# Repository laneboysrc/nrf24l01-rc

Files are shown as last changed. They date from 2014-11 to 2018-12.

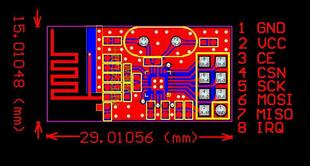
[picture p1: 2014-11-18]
doc/NRF24L01-module.jpg

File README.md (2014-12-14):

# nRF24-based RC car receiver, compatible with HobbyKing HK310 and Turnigy 3XS

This project includes **electronics** and **firmware** to build **surface RC receivers** that can replace the HobbyKing [HKR3000](http://hobbyking.com/hobbyking/store/__12187__HK_3000_3ch_2_4ghz_FHSS_RX_suit_the_HK310_Transmitter.html) and [XR3100](http://hobbyking.com/hobbyking/store/__22910__HK3100_3ch_2_4ghz_FHSS_Micro_RX_suits_HK310_Turnigy_3XS_TX_.html) receivers. They can be used with the [HK300](http://hobbyking.com/hobbyking/store/__12177__HK_300_3_Channel_2_4ghz_FHSS_Ground_Radio.html), [HK310](http://hobbyking.com/hobbyking/store/__12181__HK_310_3_Channel_2_4ghz_FHSS_Ground_Radio.html) and [Turnigy 3XS](http://hobbyking.com/hobbyking/store/__24905__Turnigy_3XS_FHSS_2_4GHz_3_Channel_Radio_System.html) RC car radio systems.

The receivers make use of off-the-shelf inexpensive RF modules.

Two variants are provided:

- [lpc812-nrf24l01](lpc812-nrf24l01-receiver/): NRF24L01+ module plus a [NXP LPC812](http://www.nxp.com/products/microcontrollers/cortex_m0_m0/series/LPC800.html) MCU
- [nrf24le1](nrf24le1-receiver/): Using a NRF24LE1 module (integrated 8051 MCU)

Technical information about the inner working of the receivers can be found
in **[hkr3000-info.md](doc/hkr3000-info.md)**.

## Advantages of the NRF24L01+ - LPC812 version

- Easily obtainable and very low cost NRF module (less than USD 1 including shipping in qty 10 on eBay, Aliexpress)
- Very precise servo pulses due to LPC812 timer hardware
- ARM Cortex-M0 32-bit CPU is easy to program for with the GCC ARM compiler
- No proprietary programmer required as the MCU has a ROM bootloader that can be flashed with an  USB-to-serial dongle
- Servo pulses can be updated down to every 5 ms (200 Hz). In theory this may provide better response but in practice the transmitter would need to be modified to fully take
advantage of this fact.
- UART output using the LANE Boys RC [preprocessor protocol](http://laneboysrc.blogspot.com/2012/12/pre-processor-for-diy-rc-light.html), e.g. to hook up the [DIY RC light controller](https://github.com/laneboysrc/rc-light-controller) with a single servo cable.

Downsides:

- Requires a PCB and intermediate SMD soldering skills
- No CPPM output (but it has a UART output that can carry CPPM-like data and more)

## Advantages of the NRF24LE1 version

- Low part count: NRF24LE1 module, voltage regulator, a few capacitors; done!
- Simple to build even on a breadboard
- CPPM output
- UART output using the LANE Boys RC [preprocessor protocol](http://laneboysrc.blogspot.com/2012/12/pre-processor-for-diy-rc-light.html), e.g. to hook up the [DIY RC light controller](https://github.com/laneboysrc/rc-light-controller) with a single servo cable. Baudrate is limited to 38400 though.

Downsides:

- NRF24LE1 module is more expensive than NRF24L01 and harder to find
- Requires special programming hardware. Multiple open-source versions can be found on the Internet.
- Servo pulses are software timed, hence slightly jittery despite using interrupts. Note that the firmware included in this project is improved over the original HKR3000 and XR3100 firmware, which regularly extends servo pulses by 16 us due to poor interrupt logic implementation.
- For the PCB provided in this project you need to get the NRF24LE1 module version that has an SMD crystal (size 21 x 15 mm)

The NRF24LE1 firmware included in this project can be compiled to be compatible with the HKR3000 and XR3100 hardware. However, since those receivers use the OTP version (NRF24LE1G) one would have to replace the chip with the NR24LE1E versions to be able to use it.

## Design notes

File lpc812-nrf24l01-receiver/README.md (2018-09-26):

The LPC812-based receiver comes in two variants:

3/4 channel version
- Supports the original HobbyKing HK310 protocol
- Supports the LANE Boys RC 4 channel protocol
- Based on 16 pin TSSOP LPC812
- Uses the cheap nRF24 modules with the 2x4 pinheader

8 channel version
- Supports the original HobbyKing HK310 protocol
- Supports the LANE Boys RC 4 channel protocol
- Supports the LANE Boys RC 8 channel protocol
- Based on 20 pin TSSOP LPC812
- Uses a different, smaller nRF24L01 module that comes variants
with PCB antenna and IPX connector

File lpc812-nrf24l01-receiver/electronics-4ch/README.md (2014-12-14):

# Schematics and PCB layout for the NRF24L01+ - LPC812 receiver

The source files are for [Kicad](http://www.kicad-pcb.org).

For convenience the [schematics](SCHEMATICS.pdf) are also available as PDF.

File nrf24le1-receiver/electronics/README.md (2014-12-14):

# Schematics and PCB layout for the NRF24LE1 receiver

The source files are for [Kicad](http://www.kicad-pcb.org).

For convenience the [schematics](SCHEMATICS.pdf) are also available as PDF.

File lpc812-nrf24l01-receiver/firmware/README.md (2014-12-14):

# Tools required to build the LPC812 firmware

**Note: a pre-compiled firmware is available for download [here](receiver.hex).**

- **GCC for ARM** [https://launchpad.net/gcc-arm-embedded/](https://launchpad.net/gcc-arm-embedded/)

- **GNU Make** [https://www.gnu.org/software/make/](https://www.gnu.org/software/make/);
  Windows executable is available at [http://gnuwin32.sourceforge.net/packages/make.htm](http://gnuwin32.sourceforge.net/packages/make.htm)

- Optional: LCP81x-ISP [https://github.com/laneboysrc/LPC81x-ISP-tool](https://github.com/laneboysrc/LPC81x-ISP-tool) Alternatively you can use any tool that can flash the LPC812 via ISP.

- Windows users: **rm.exe** from [coreutils](http://gnuwin32.sourceforge.net/downlinks/coreutils-bin-zip.php).

# Building the firmware

Running ``make`` in a console window in this directory builds the firmware. The resulting *receiver.bin* and *receiver.hex* are located in the build directory.

Running ``make program`` flashes the firmware, assuming you are using the *LCP81x-ISP* tool.

It may be advisable to check the ``makefile`` whether the settings are desired for your application.

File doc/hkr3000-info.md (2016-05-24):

# HKR3000 and XR3100 receiver technical information

Both receivers use the [Nordic NRF24LE1](http://www.nordicsemi.com/eng/Products/2.4GHz-RF/nRF24LE1) RF chip. It is a composite device containing the RF logic of the popular NRF24L01+ and an 8051 MCU.

Unfortunately both receivers use the OTP version, not the Flash version, so they can not be re-programmed.

The HKR3000 has an LNA (Low Noise Amplifier), the XR3100 connects the antenna directly the NRF24LE1. In theory this should give the HKR3000 better range, but in practice I haven't noticed any difference between them.

## Transmitter

The HK310 and 3XS transmitter also contains an NRF24LE1, which receives channel 1, 2 and 3 data (we call this **stick data**) from another microcontroller via UART. The stick data over the UART is 12 bit, with center (1500 us) being 0x465.
The NRF24LE1 in the transmitter converts this stick data into a 16-bit timer value that can be directly loaded into one of the timers on the NRF24LE1's 8051 MCU. These 16-bits are sent over the air. The timer tick is assumed to be 750 ns (16 MHz / 12).

The algorithm to calculate the timer value is as follows:

        timer_value = (uart_data * 14 / 10) + 0xf200

## NRF24 RF configuration

- 10 byte payload size
- 5 byte address size
- 2 byte CRC
- 20 hop channels
- One hop every 5 ms
- Transmitter sends three packets every 5 ms: two stick (or failsafe) packets, one bind packet
- Uni-directional data transfer (transmitter only transmits, receiver only receives; no acknowledgement or telemetry)

## Stick and failsafe packet format

Example payload of actual captured packets (10 bytes payload):
```
f1 f7 4a f8 8e f5 b8 55 67 0f     stick packet
40 f8 40 f8 8e f5 b8 aa 5a 0f     failsafe packet
```

Stick data:
```
0     1     2     3     4     5     6    7    8    9
ST-l  ST-h  TH-l  TH-h  CH3-l CH3-h ???  0x55 0x67 ???
                                         ^^^^
                                         Packet id
```
Bytes 6, 8 and 9 are ignored by the receiver

Failsafe data:
```
0     1     2     3     4     5     6    7    8    9
ST-l  ST-h  TH-l  TH-h  CH3-l CH3-h ???  0xaa 0x5a ???   (failsafe on)
                                              0x5b       (failsafe off)
                                         ^^^^
                                         Packet id
```
Bytes 6 and 9 are ignored by the receiver

Stick values are sent as direct timer values for an 8051 timer with a 750 ns clock. To calculate milliseconds of servo pulse duration, use the following formula:

    servo_pules_in_us = (0xffff - stickdata) * 3 / 4;

## Binding procedure:

The transmitter regularly sends data on the fixed channel **0x51** (81 decimal), with address **12:23:23:45:78** (hex). This data is sent at a lower power (PA in the transmitter turned off, NRF24 power set to a low power level). All transmitters do that all the time. Due to the low transmit power, the transmitter has to be brought physically very close (within a few cm) before binding can succeed.

The transmitter cycles through four type of bind packets:
```
ff aa 55 a1 a2 a3 a4 a5 .. ..
cc cc 00 ha hb hc hd he hf hg
cc cc 01 hh hi hj hk hl hm hn
cc cc 02 ho hp hq hr hs ht ..
```

``ff aa 55``     Special marker for the first bind packet

``a[1-5]``       The 5 address bytes

``cc cc``        The 16 bit sum of bytes a1..a5

``h[a-t]``       20 channels for frequency hopping

``..``           Not used

## Miscellaneous

- The firmware for the HKR3000 and XR3100 firmware are identical except for different I/O pin usage.

- The receiver was originally designed for 4 channels, but it seems that it was *hacked* to support failsafe, destroying the 4th channel value in payload byte 7. This was a weird decision as byte 9 could have been used, fully maintaining 4 channels.

- If failsafe is off in the transmitter, the receiver still applies a default failsafe value of 1500 us to steering and throttle channels when the signal is lost.

- The failsafe time is 640 ms. I.e failsafe is triggered when no stick data packet is received within 640 ms.

- Because the OTP version of the NRF24LE1 is used, a small external EEPROM had to be added to store 25 bytes of bind data (5 address bytes, 20 hop channel bytes). Using the Flash version of the NRF24LE1 can save this external component because the Flash version contains a high endurance NVM memory.

- The 2-wire function (I2C) of the nRF24LE1 is not used but I2C is bit-banged.

- The transmitter always generates hop channels in sequencial order. This is poor for resiliance against interference. This is especially unfortunate because the transmitter uses the hardware random number generator of the NRF24 chip to obtain a truely random address and start of hop.

- The transmitter only generates the first hop channels between 0 and 49 (modulo 0x32). So the channel range is from 0 to 69. Maximum possible would be 125 according to the data sheet. It is unclear why this limit has been implemented. It may be due to regulatory issues, or possibly because of limitiations in the transmitter PA or receiver LNA.

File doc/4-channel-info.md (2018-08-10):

# 4-channel adaptation

As of August 2018 the receiver supports a variant of the RF protocol that supports 4 channels.

Note: this mode is only useful if you use the LANE Boys RC [Headless transmitter](https://github.com/laneboysrc/rc-headless-transmitter), which is the only transmitter supporting this protocol.

The original HKR3000 protocol uses a payload of 10 bytes to transmit stick- and failsafe data. Two of the bytes (6 and 9) are unused. We make use of these bytes to transmit data for a 4th channel.

The receiver hardware has four connectors: 3 channels and a battery/pre-processor output.
In 4-channel mode we use the battery/preprocessor output as CH4, so no hardware modification is necessary.

In order to let the receiver know whether it should operate in 3 or 4 channel mode, we use different packet id fields for 4-channel mode and use a different marker for the first bind packet. The remainder of the protocol is identical with the HKR3000.

Stick data uses packet id 0x56 (instead of 0x55).
Failsafe data uses packet id 0xab (instead of 0xaa).

The bind packages are formatted as follows:
```
ff ab 56 a1 a2 a3 a4 a5 .. ..
cc cc 00 ha hb hc hd he hf hg
cc cc 01 hh hi hj hk hl hm hn
cc cc 02 ho hp hq hr hs ht ..
```
``ff ab 56``     Special marker for the first bind packet (Note: HKR3000 uses ``ff aa 55``)

``a[1-5]``       The 5 address bytes

``cc cc``        The 16 bit sum of bytes a1..a5

``h[a-t]``       20 channels for frequency hopping

``..``           Not used

## 3-channel mode (HKR3000 protocol)

Stick data:
```
0     1     2     3     4     5     6    7    8    9
ST-l  ST-h  TH-l  TH-h  CH3-l CH3-h xxx  0x55 0x67 xxx
                                         ^^^^
                                         Packet id
```

Failsafe data:
```
0     1     2     3     4     5     6    7    8    9
ST-l  ST-h  TH-l  TH-h  CH3-l CH3-h xxx  0xaa 0x5a xxx   (failsafe on)
                                              0x5b       (failsafe off)
                                         ^^^^
                                         Packet id
```

## 4-channel mode

Stick data:
```
0     1     2     3     4     5     6     7    8    9
ST-l  ST-h  TH-l  TH-h  CH3-l CH3-h CH4-l 0x56 0x67 CH4-h
                                          ^^^^
                                          Packet id
```

Failsafe data:
```
0     1     2     3     4     5     6     7    8    9
ST-l  ST-h  TH-l  TH-h  CH3-l CH3-h CH4-l 0xab 0x5a CH4-h (failsafe on)
                                               0x5b       (failsafe off)
                                          ^^^^
                                          Packet id
```

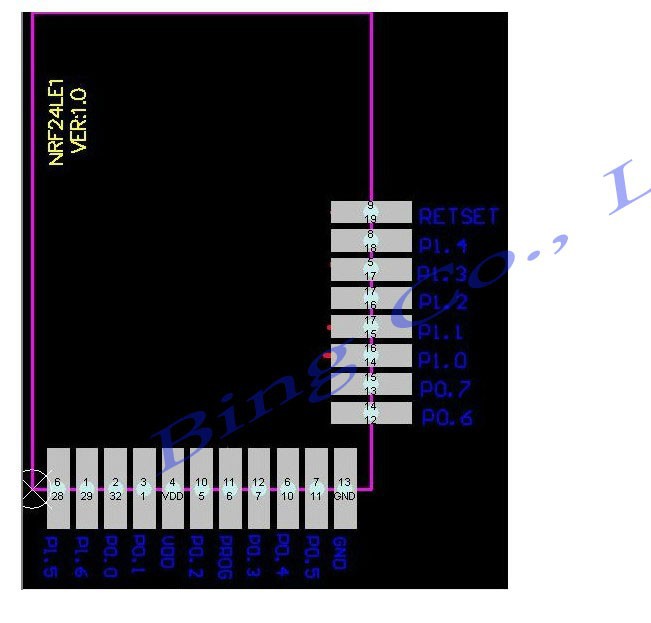
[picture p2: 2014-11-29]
doc/NRF24LE1-module-pinout.jpg

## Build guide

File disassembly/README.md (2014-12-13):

# HKR3000 and XR3100 receiver disassembly

This folder contains **control files** for the D52 disassembler to disassemble firmware images extracted from the HobbyKing HKR3000 and XR3100 receiver.

Note that the firmware images are not provided, you have to read it out from your own receivers using any of the widely availblae NRF24LE1 programmers.

Required tools:

- D52 ([http://www.bipom.com/dis51.php](http://www.bipom.com/dis51.php))

- GNU Make ([https://www.gnu.org/software/make/](https://www.gnu.org/software/make/);
  Windows executable is available at [http://gnuwin32.sourceforge.net/packages/make.htm](http://gnuwin32.sourceforge.net/packages/make.htm))

- If you are using Windows you also need **cp.exe** and **rm.exe** from [coreutils](http://gnuwin32.sourceforge.net/downlinks/coreutils-bin-zip.php).

After you've installed the required tools, run **make**, which will create assembler files with the extension **.d52**.

For test purpose you can run **make bin**, which will re-assemble the **.d52** files. You can then compare the original firmware image with the re-assembled one. They should perfectly match.

For re-assembly you need additional tools:

-  MCU 8051 IDE ([http://sourceforge.net/projects/mcu8051ide/](http://sourceforge.net/projects/mcu8051ide/))

- objcopy ([https://www.gnu.org/software/binutils/](https://www.gnu.org/software/binutils/))
  If you are using Windows you can get them via [MinGW](http://www.mingw.org/)

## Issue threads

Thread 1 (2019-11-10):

Question about porting this to other platforms

LouDnl, 2019-11-10:
Before I dive into this repository and surround my with all sorts of challenges I do not (yet) have the knowledge for.

Do you guys have any tips on how to port this to an stm32f103c8t6 or avr? Or maybe someone else has already done this?

laneboysrc, 2019-11-10:
Hi,

there is no port to the STM32 platform that I am aware of.

Porting should however be quite easy. There is already an ARM Cortex M0 based implementation in the lpc812-nrf24l01-receiver/ folder. The code in there can be ported to STM32 with minimal effort.

Porting to AVR will be more of a challenge as it is quiet an old 8-bit platform, but do-able as well.

Note that this receivers are designed to work with the HobbyKing HK310 RC car transmitter, they do not work with any other transmitters.
The HK310 is no longer for sale.

I do however also have a matching transmitter project for this receiver, which incidentally is based on STM32 (Bluepill boards): https://github.com/laneboysrc/rc-headless-transmitter
That one requires serious effort and knowledge to build though.

cheers, Werner

LouDnl, 2019-11-11:
Thanks for your reply! I was indeed planning to port it to STM32 or another 32bit platform. I will have a dive into the code and see what I can whip up.

LouDnl, 2019-11-11:
Just need to split the receiver code from the lpc812 code.

Closed 2019-11-10.

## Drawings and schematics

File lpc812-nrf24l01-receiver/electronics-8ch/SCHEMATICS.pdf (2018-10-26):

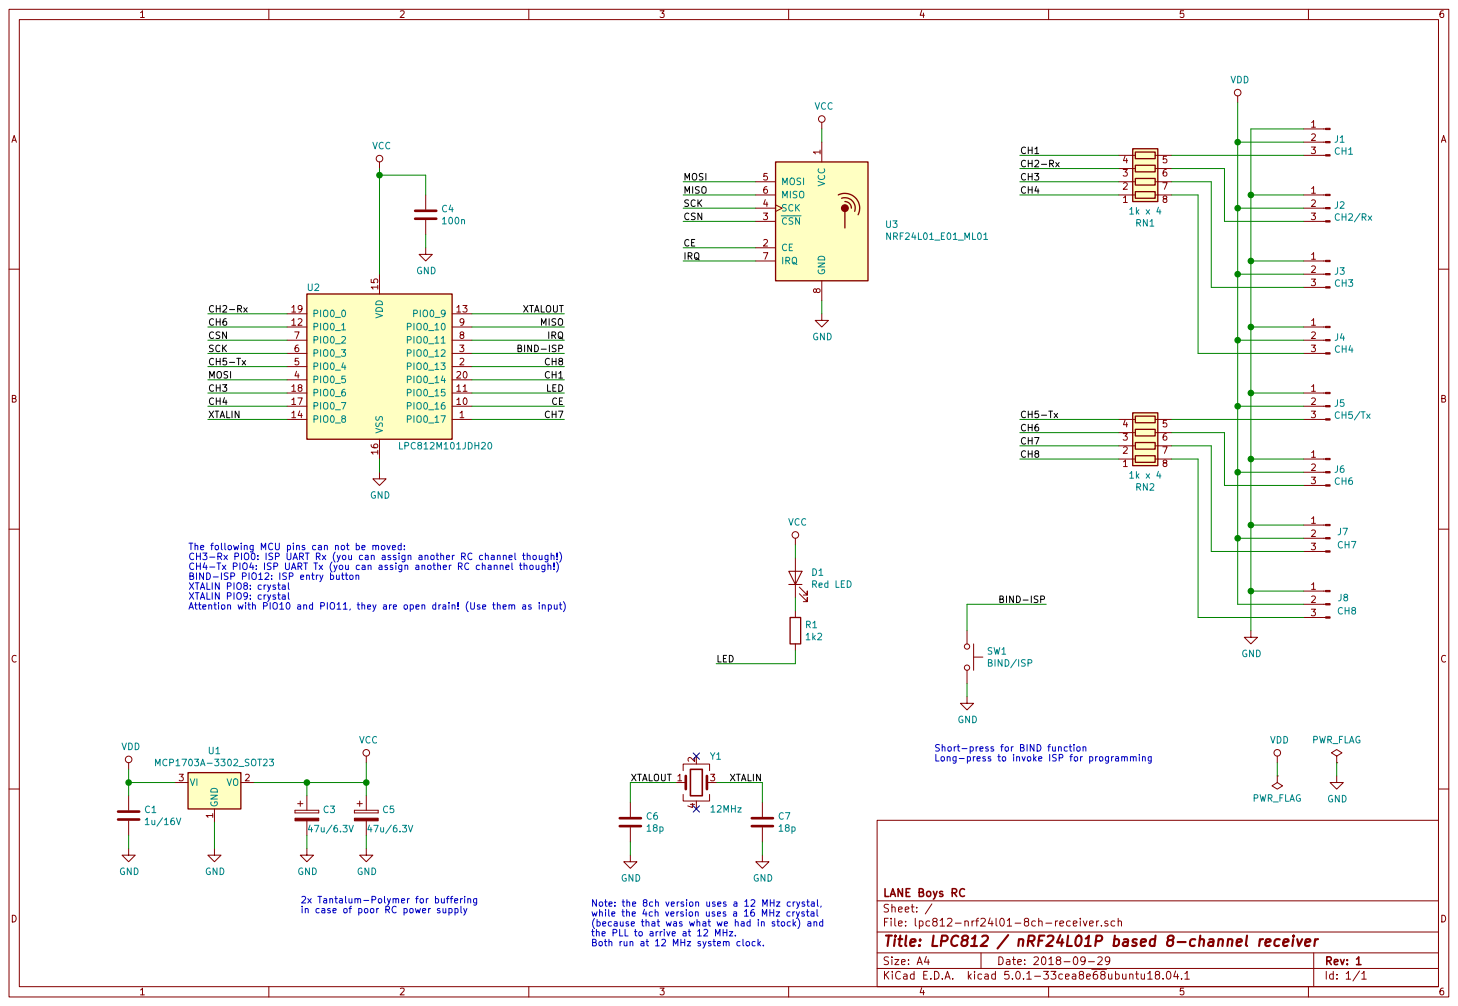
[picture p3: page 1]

1 CE 2 CSN 3 SCK 4 MOSI 5 MISO 6

The following MCU pins can not be moved:
CH3-Rx PIO0: ISP UART Rx (you can assign another RC channel though!)
CH4-Tx PIO4: ISP UART Tx (you can assign another RC channel though!)
BIND-ISP PIO12: ISP entry button
XTALIN PIO8: crystal
XTALIN PIO9: crystal

Short-press for BIND function
Long-press to invoke ISP for programming

12MHz Note: the 8ch version uses a 12 MHz crystal,

File: lpc812-nrf24l01-8ch-receiver.sch Sheet: / LANE Boys RC

2x Tantalum-Polymer for buffering
in case of poor RC power supply

while the 4ch version uses a 16 MHz crystal
(because that was what we had in stock) and
the PLL to arrive at 12 MHz. Both run at 12 MHz system clock.

Id: 1/1 Title: LPC812 / nRF24L01P based 8-channel receiver

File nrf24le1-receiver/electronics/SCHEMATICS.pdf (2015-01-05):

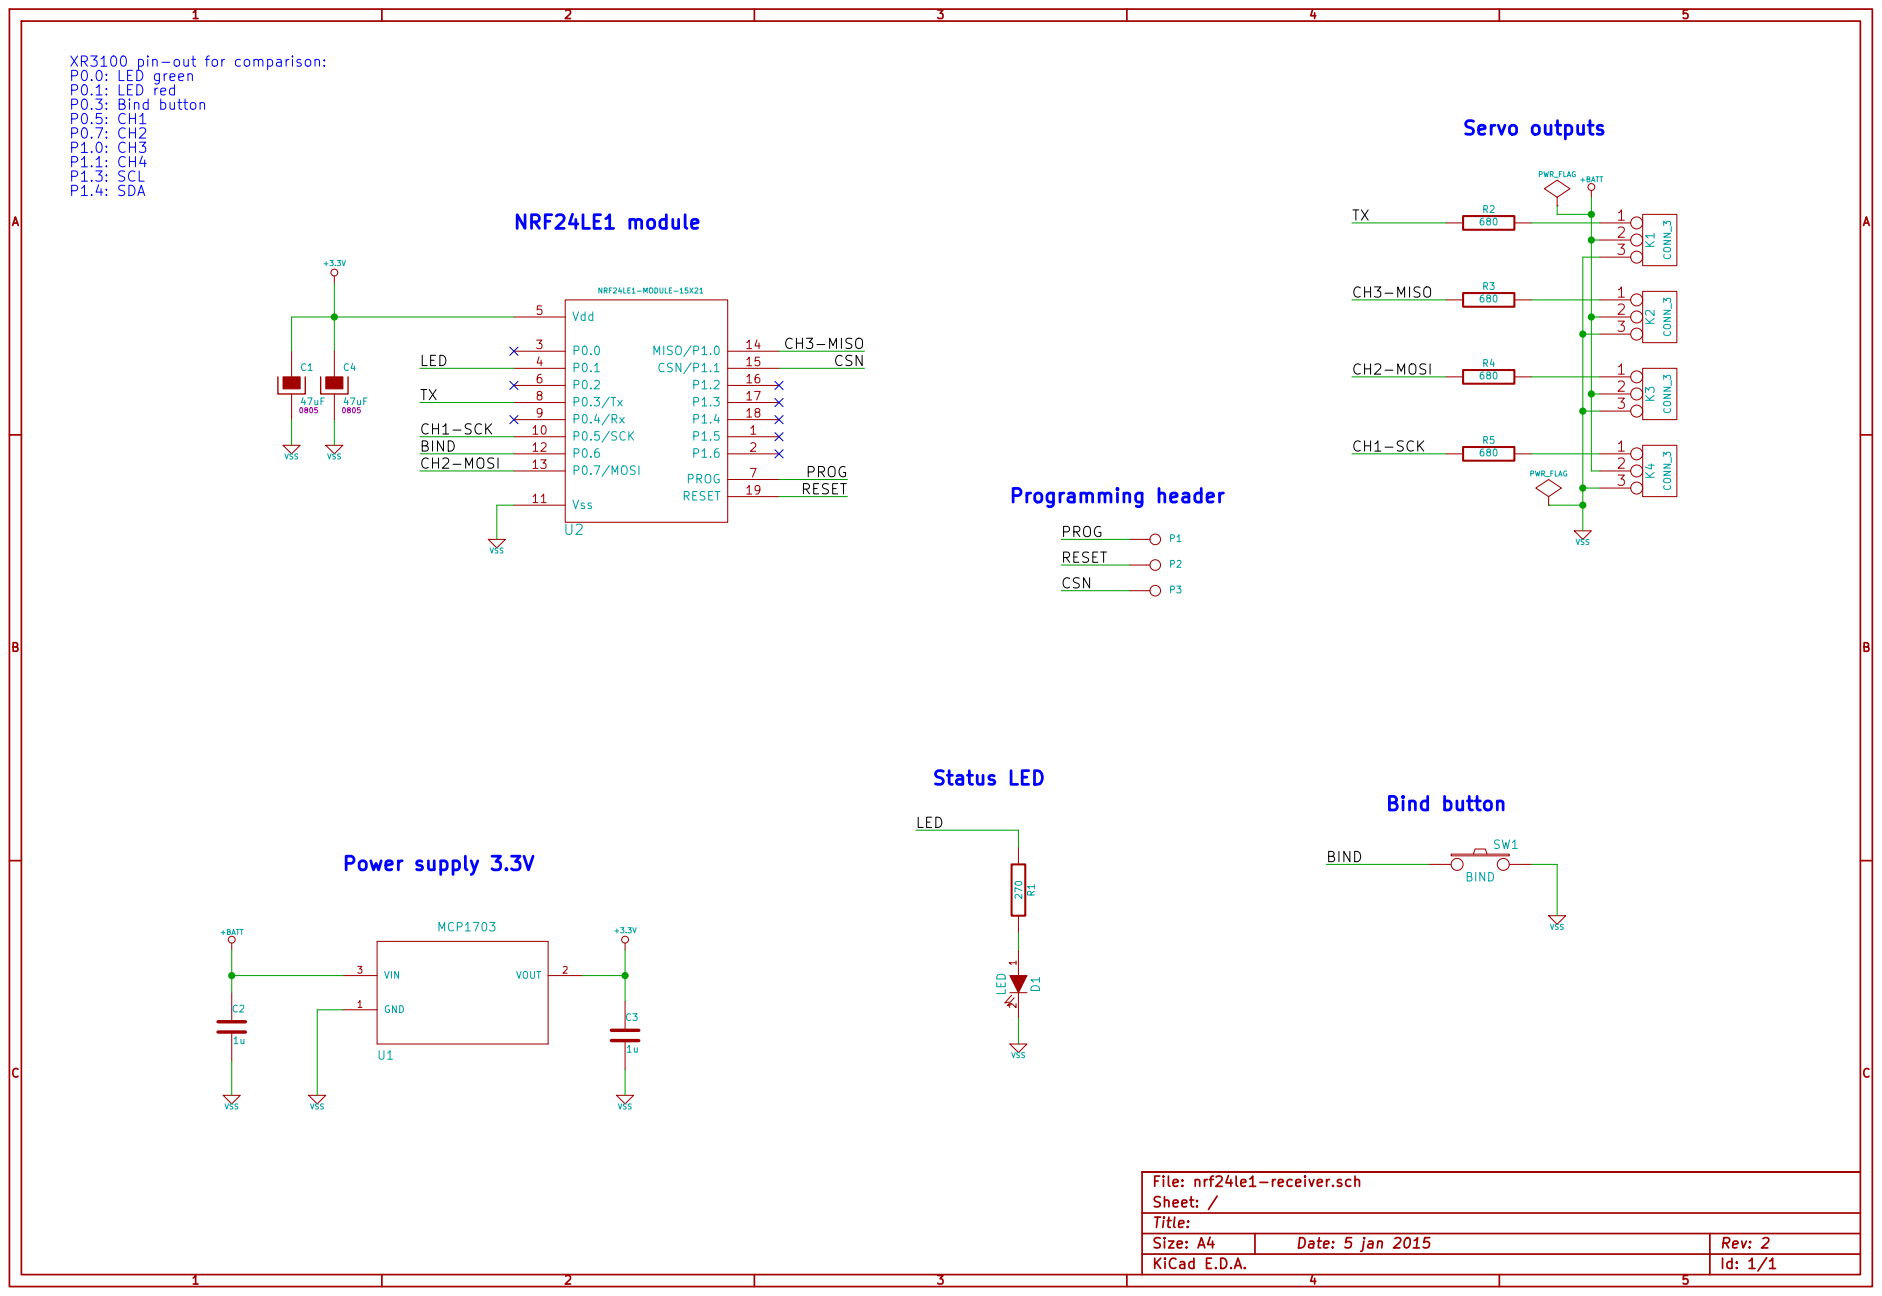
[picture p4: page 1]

PWR_FLAG XR3100 pin-out for comparison:
P0.0: LED green P0.1: LED red P0.3: Bind button P0.5: CH1

Id: 1/1 Title: File: nrf24le1-receiver.sch Sheet: /

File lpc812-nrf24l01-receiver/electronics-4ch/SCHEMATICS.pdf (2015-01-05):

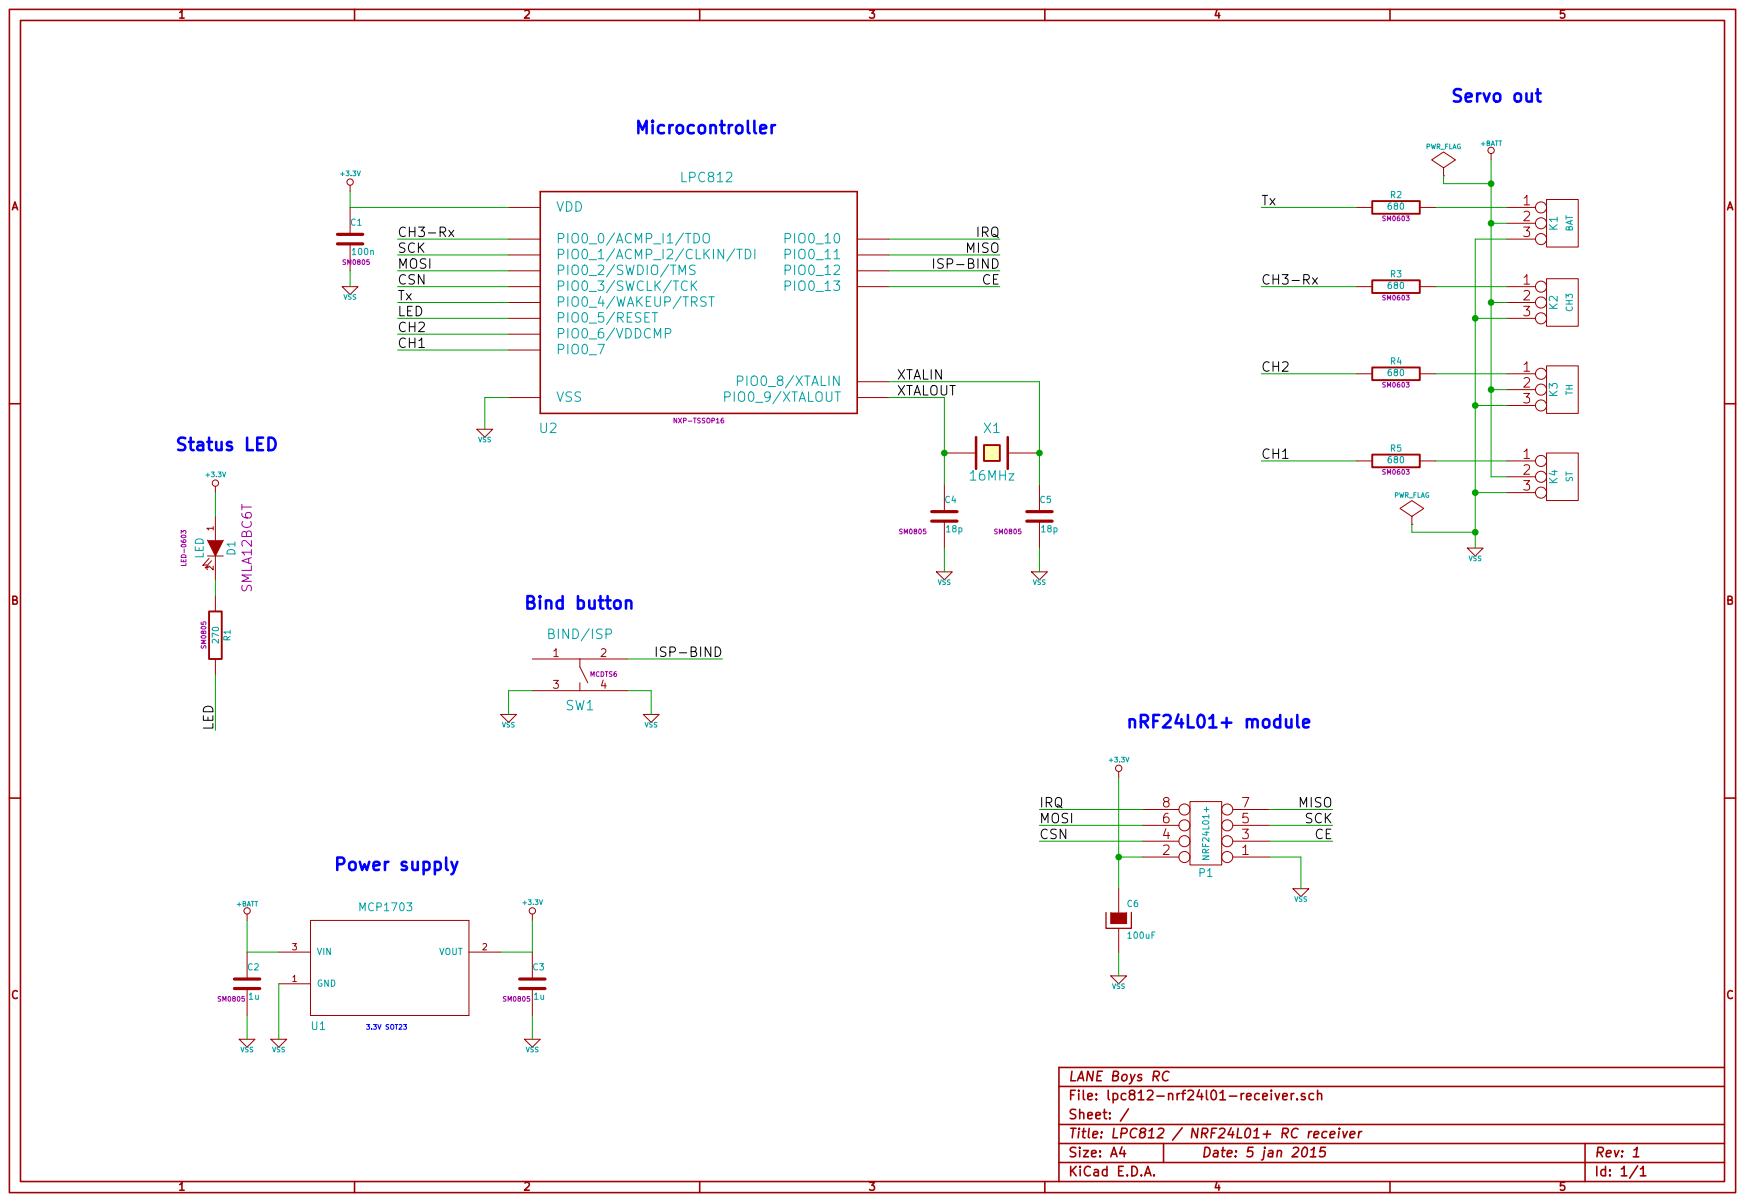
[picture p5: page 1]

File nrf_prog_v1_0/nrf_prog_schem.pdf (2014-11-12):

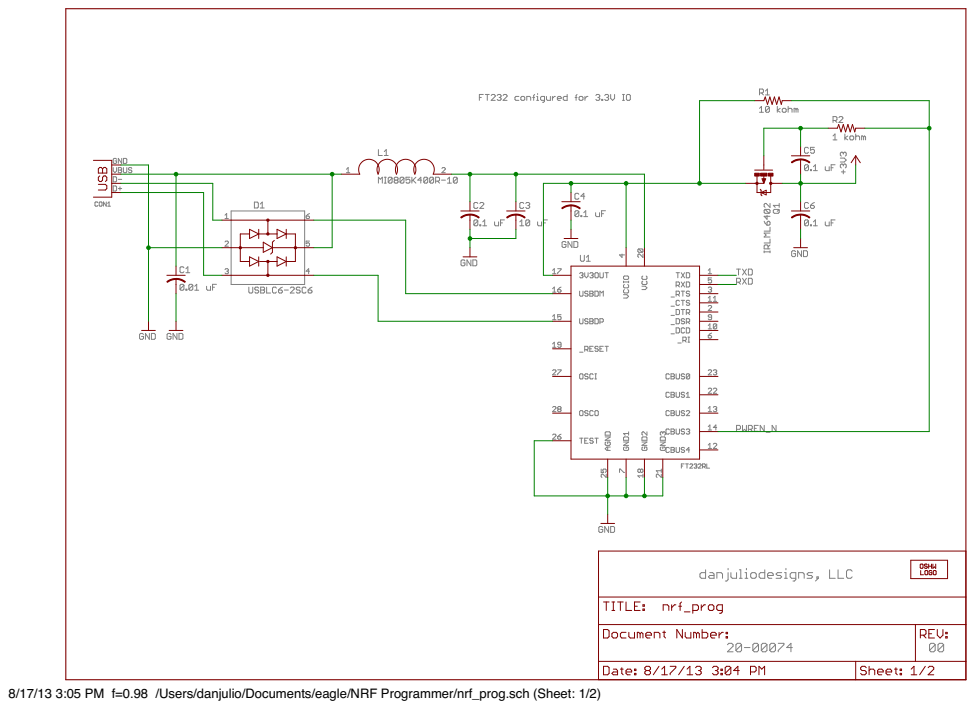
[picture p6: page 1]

8/17/13 3:05 PM f=0.98 /Users/danjulio/Documents/eagle/NRF Programmer/nrf_prog.sch (Sheet: 1/2)

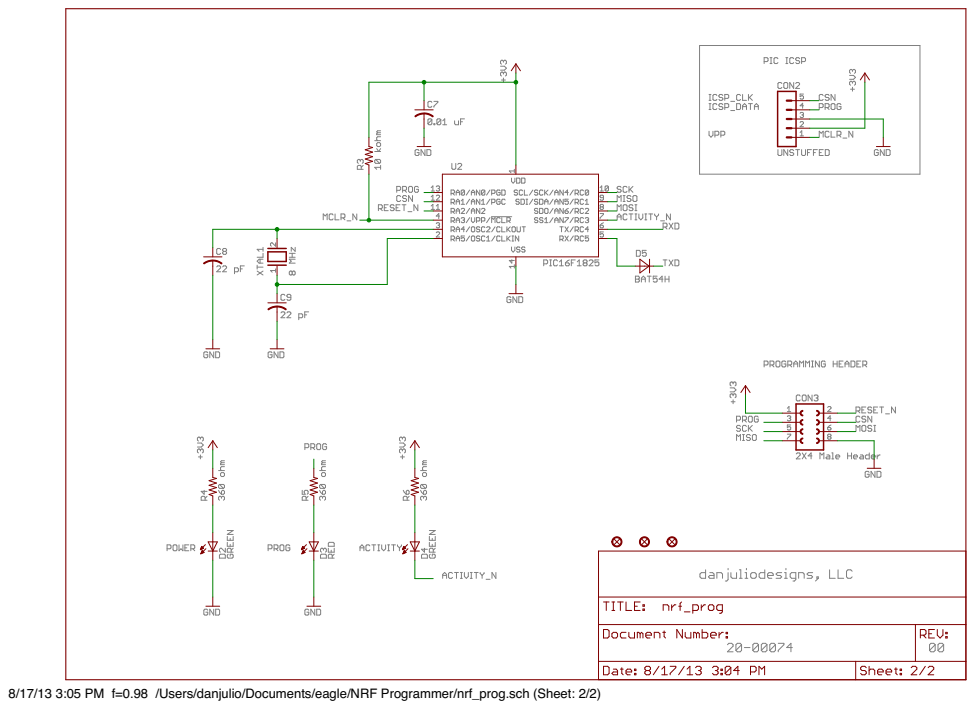
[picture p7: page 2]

8/17/13 3:05 PM f=0.98 /Users/danjulio/Documents/eagle/NRF Programmer/nrf_prog.sch (Sheet: 2/2)

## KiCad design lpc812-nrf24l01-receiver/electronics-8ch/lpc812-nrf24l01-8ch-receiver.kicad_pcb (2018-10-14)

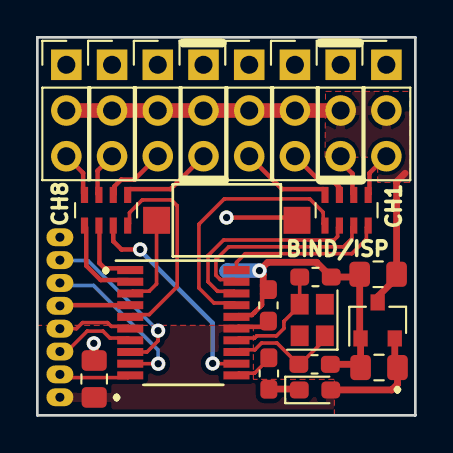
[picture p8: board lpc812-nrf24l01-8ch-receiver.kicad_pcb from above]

Board: 2 copper layers, 21.0 x 21.0 mm, 23 parts (1 on the bottom side), 30 nets.

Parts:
C1: 1u/16V; C_0805_2012Metric_Pad1.15x1.40mm_HandSolder
C3, C5: 47u/6.3V; C_0805_2012Metric_Pad1.15x1.40mm_HandSolder
C4: 100n; C_0603_1608Metric_Pad1.05x0.95mm_HandSolder
C6, C7: 18p; C_0603_1608Metric_Pad1.05x0.95mm_HandSolder
D1: LED; LED_0603_1608Metric_Pad1.05x0.95mm_HandSolder
J1: CH1; PinHeader_1x03_P2.54mm_Vertical
J2: CH2/Rx; PinHeader_1x03_P2.54mm_Vertical
J3: CH3; PinHeader_1x03_P2.54mm_Vertical
J4: CH4; PinHeader_1x03_P2.54mm_Vertical
J5: CH5/Tx; PinHeader_1x03_P2.54mm_Vertical
J6: CH6; PinHeader_1x03_P2.54mm_Vertical
J7: CH7; PinHeader_1x03_P2.54mm_Vertical
J8: CH8; PinHeader_1x03_P2.54mm_Vertical
R1: 270; R_0603_1608Metric_Pad1.05x0.95mm_HandSolder
RN1, RN2: 1k x 4; R_Array_Concave_4x0603
SW1: BIND/ISP; Tact switch 6x4x3
U1: MCP1703A-3302_SOT23; SOT-23
U2: LPC812M101JDH20; TSSOP-20_4.4x6.5mm_P0.65mm
U3: NRF24L01_E01_ML01; nrf24l01-E01-ML01IPX
Y1: 12MHz; Crystal_SMD_2520-4Pin_2.5x2.0mm

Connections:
/BIND-ISP: SW1.1, U2.3
/CE: U2.10, U3.2
/CH1: RN1.4, U2.20
/CH2-Rx: RN1.3, U2.19
/CH3: RN1.2, U2.18
/CH4: RN1.1, U2.17
/CH5-Tx: RN2.4, U2.5
/CH6: RN2.3, U2.12
/CH7: RN2.2, U2.1
/CH8: RN2.1, U2.2
/CSN: U2.7, U3.3
/IRQ: U2.8, U3.7
/LED: R1.2, U2.11
/MISO: U2.9, U3.6
/MOSI: U2.4, U3.5
/SCK: U2.6, U3.4
/XTALIN: C7.1, U2.14, Y1.3
/XTALOUT: C6.1, U2.13, Y1.1
GND: C1.2, C3.2, C4.2, C5.2, C6.2, C7.2, J1.1, J2.1, J3.1, J4.1, J5.1, J6.1, J7.1, J8.1, SW1.2, U1.1, U2.16, U3.8
unnamed: D1.1, R1.1
unnamed: J1.3, RN1.5
unnamed: J2.3, RN1.6
unnamed: J3.3, RN1.7
unnamed: J4.3, RN1.8
unnamed: J5.3, RN2.5
unnamed: J6.3, RN2.6
unnamed: J7.3, RN2.7
unnamed: J8.3, RN2.8
VCC: C3.1, C4.1, C5.1, D1.2, U1.2, U2.15, U3.1
VDD: C1.1, J1.2, J2.2, J3.2, J4.2, J5.2, J6.2, J7.2, J8.2, U1.3

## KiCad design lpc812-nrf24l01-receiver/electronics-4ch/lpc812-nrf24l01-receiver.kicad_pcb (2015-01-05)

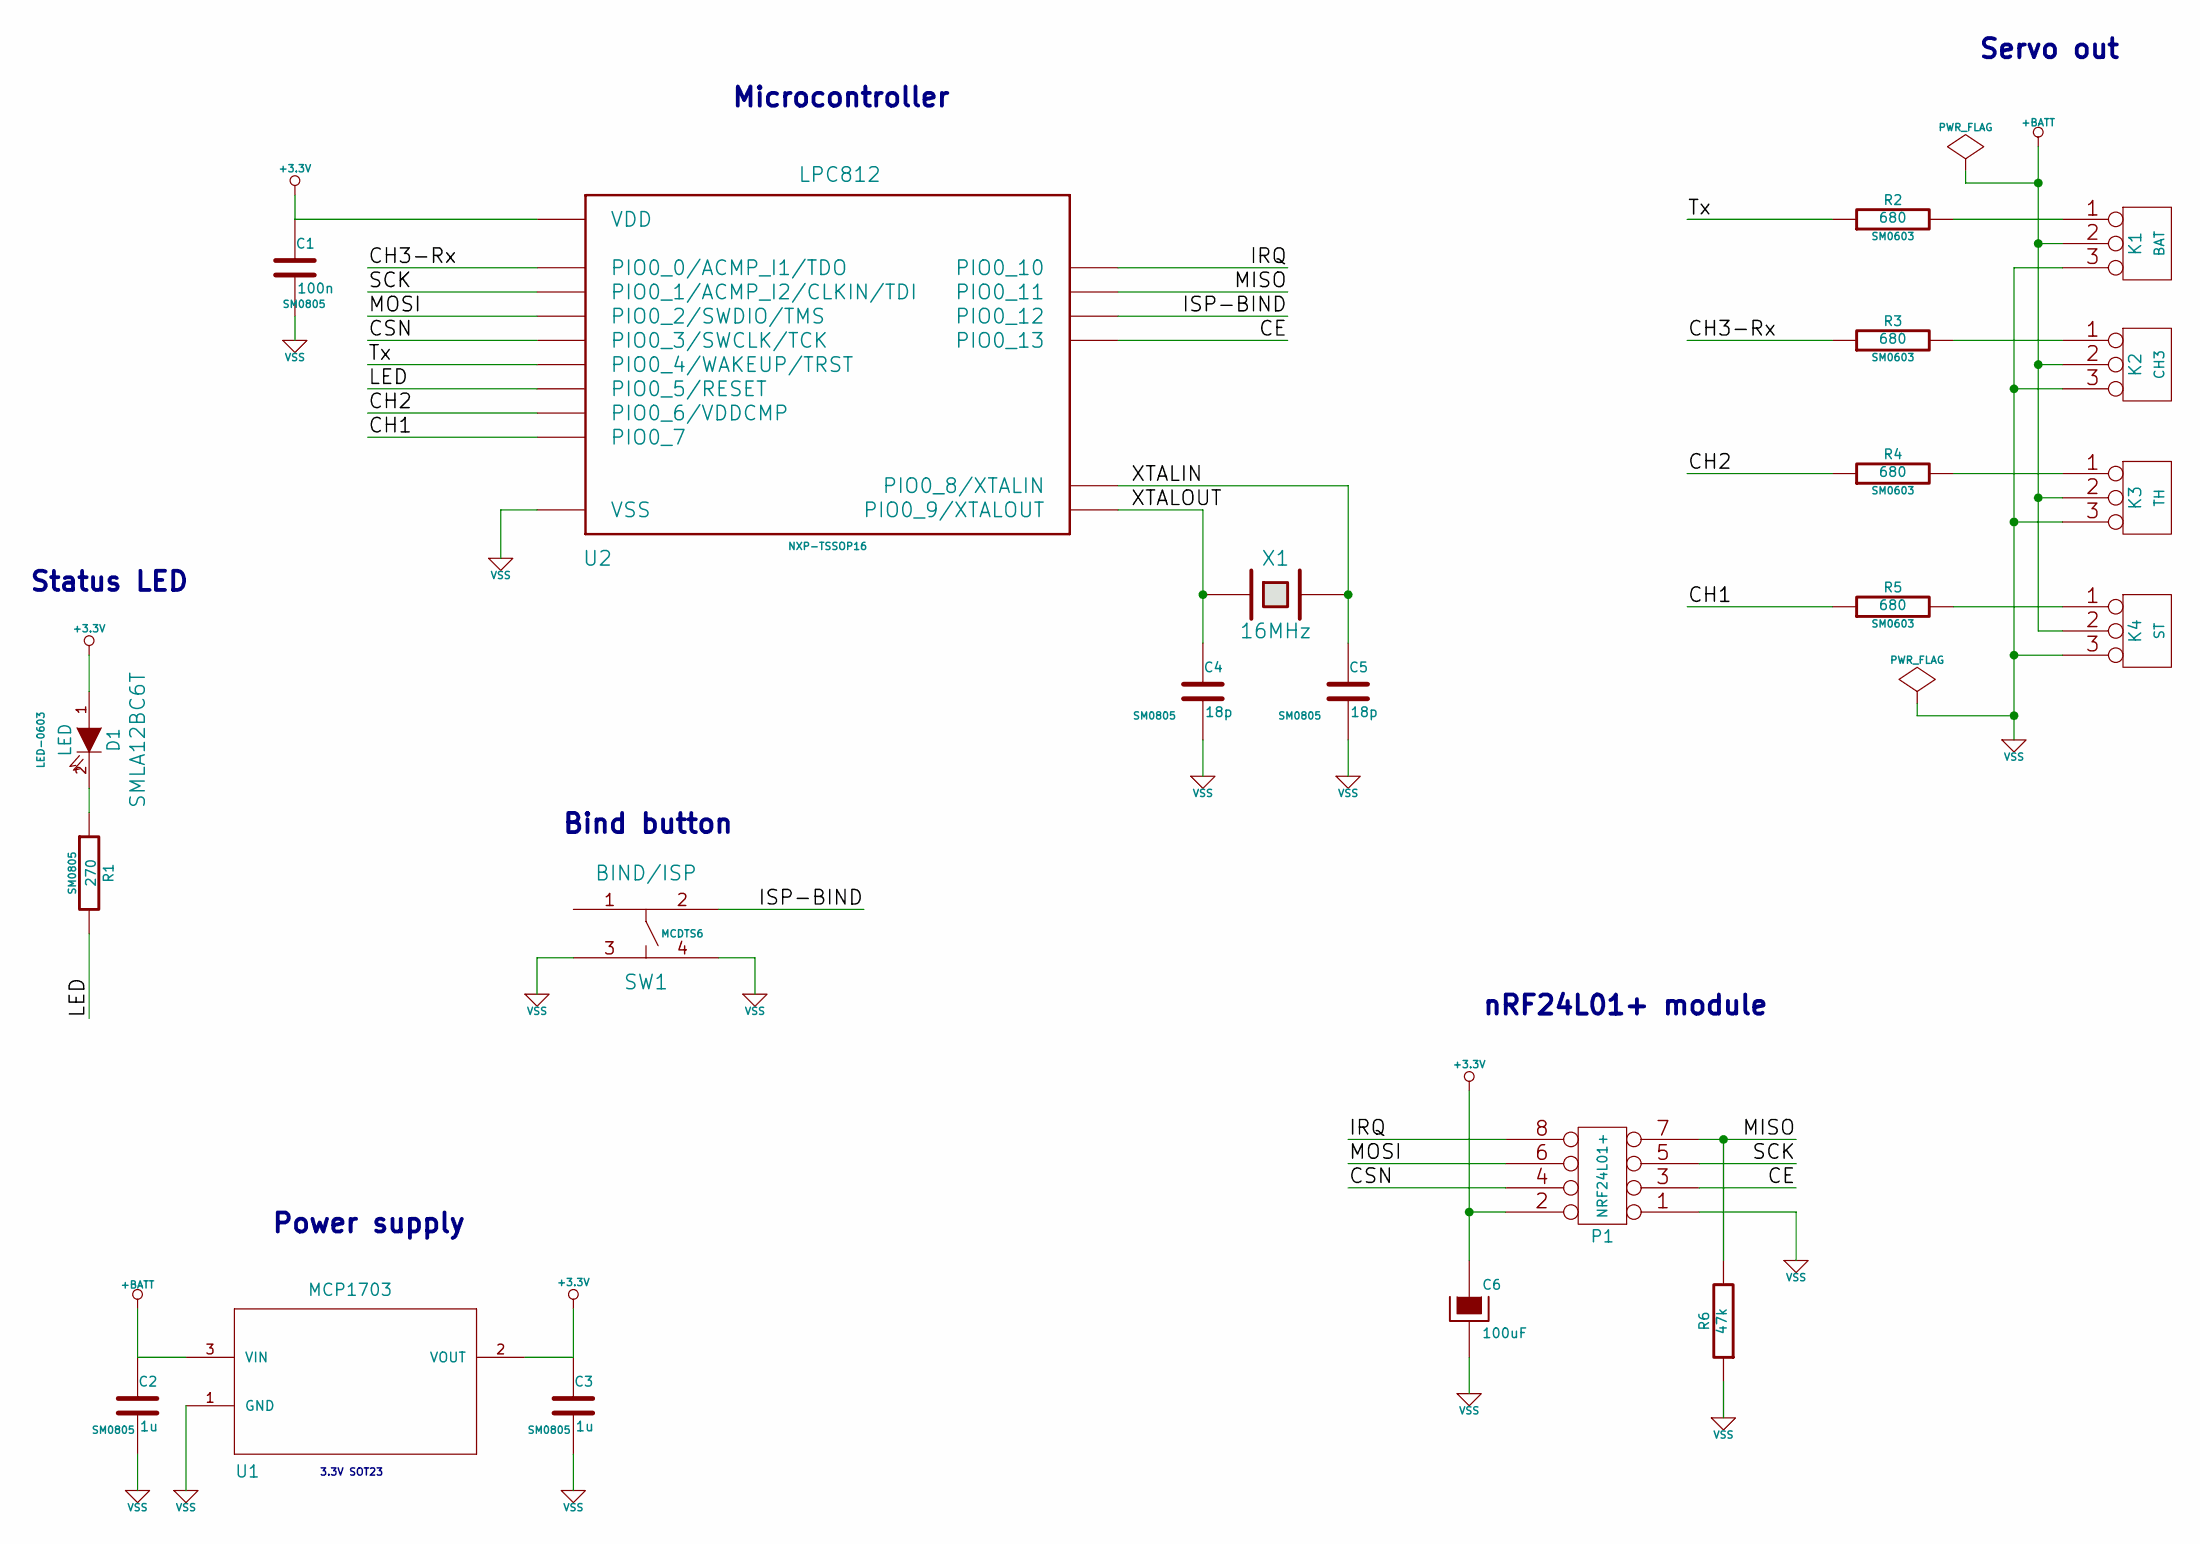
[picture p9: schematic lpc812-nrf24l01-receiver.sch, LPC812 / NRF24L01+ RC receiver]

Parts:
C1: 100n; SM0805
C2, C3: 1u; SM0805
C4, C5: 18p; SM0805
C6: 100uF
D1: LED; LED-0603
K1: BAT; PIN_ARRAY_3X1
K2: CH3; PIN_ARRAY_3X1
K3: TH; PIN_ARRAY_3X1
K4: ST; PIN_ARRAY_3X1
P1: NRF24L01+; pin_array_4x2
R1: 270; SM0805
R2, R3, R4, R5: 680; SM0603
R6: 47k
SW1: BIND/ISP; MCDTS6
U1: MCP1703; MCP1703-SOT95P300X145-3N
U2: LPC812; NXP-TSSOP16
X1: 16MHz; Q_49U3HMS

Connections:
+3.3V: C1.1, C3.1, C6.1, D1.1 (A), P1.2, U1.2 (VOUT), U2.12 (VDD)
+BATT: C2.1, K1.2 (PM), K2.2 (PM), K3.2 (PM), K4.2 (PM), U1.3 (VIN)
/CE: P1.3, U2.1 (PIO0_13)
/CH1: R5.1, U2.14 (PIO0_7)
/CH2: R4.1, U2.15 (PIO0_6/VDDCMP)
/CH3-Rx: R3.1, U2.16 (PIO0_0/ACMP_I1/TDO)
/CSN: P1.4, U2.5 (PIO0_3/SWCLK/TCK)
/IRQ: P1.8, U2.8 (PIO0_10)
/ISP-BIND: SW1.2, U2.2 (PIO0_12)
/LED: R1.2, U2.3 (PIO0_5/RESET)
/MISO: P1.7, R6.2, U2.7 (PIO0_11)
/MOSI: P1.6, U2.6 (PIO0_2/SWDIO/TMS)
/SCK: P1.5, U2.9 (PIO0_1/ACMP_I2/CLKIN/TDI)
/Tx: R2.1, U2.4 (PIO0_4/WAKEUP/TRST)
/XTALIN: C5.1, U2.11 (PIO0_8/XTALIN), X1.2
/XTALOUT: C4.1, U2.10 (PIO0_9/XTALOUT), X1.1
unnamed: D1.2 (K), R1.1
unnamed: K1.1, R2.2
unnamed: K4.1, R5.2
unnamed: K3.1, R4.2
unnamed: K2.1, R3.2
VSS: C1.2, C2.2, C3.2, C4.2, C5.2, C6.2, K1.3, K2.3, K3.3, K4.3, P1.1, R6.1, SW1.3, SW1.4, U1.1 (GND), U2.13 (VSS)

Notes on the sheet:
Microcontroller
Servo out
nRF24L01+ module
Status LED
Bind button
Power supply
3.3V SOT23

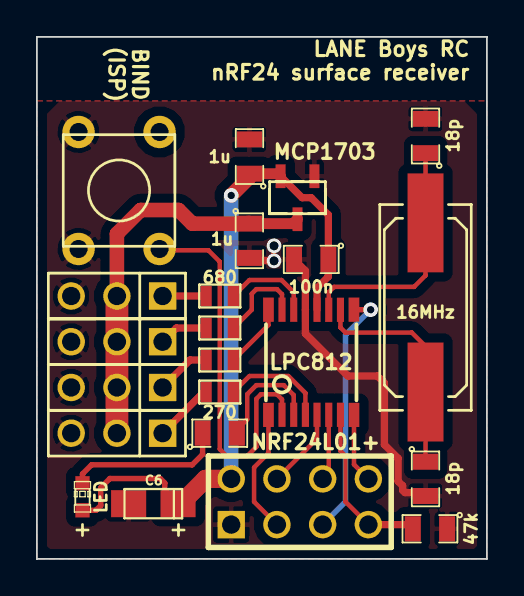
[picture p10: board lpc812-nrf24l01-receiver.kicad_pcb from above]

Board: 2 copper layers, 25.0 x 29.0 mm, 22 parts (0 on the bottom side), 22 nets.

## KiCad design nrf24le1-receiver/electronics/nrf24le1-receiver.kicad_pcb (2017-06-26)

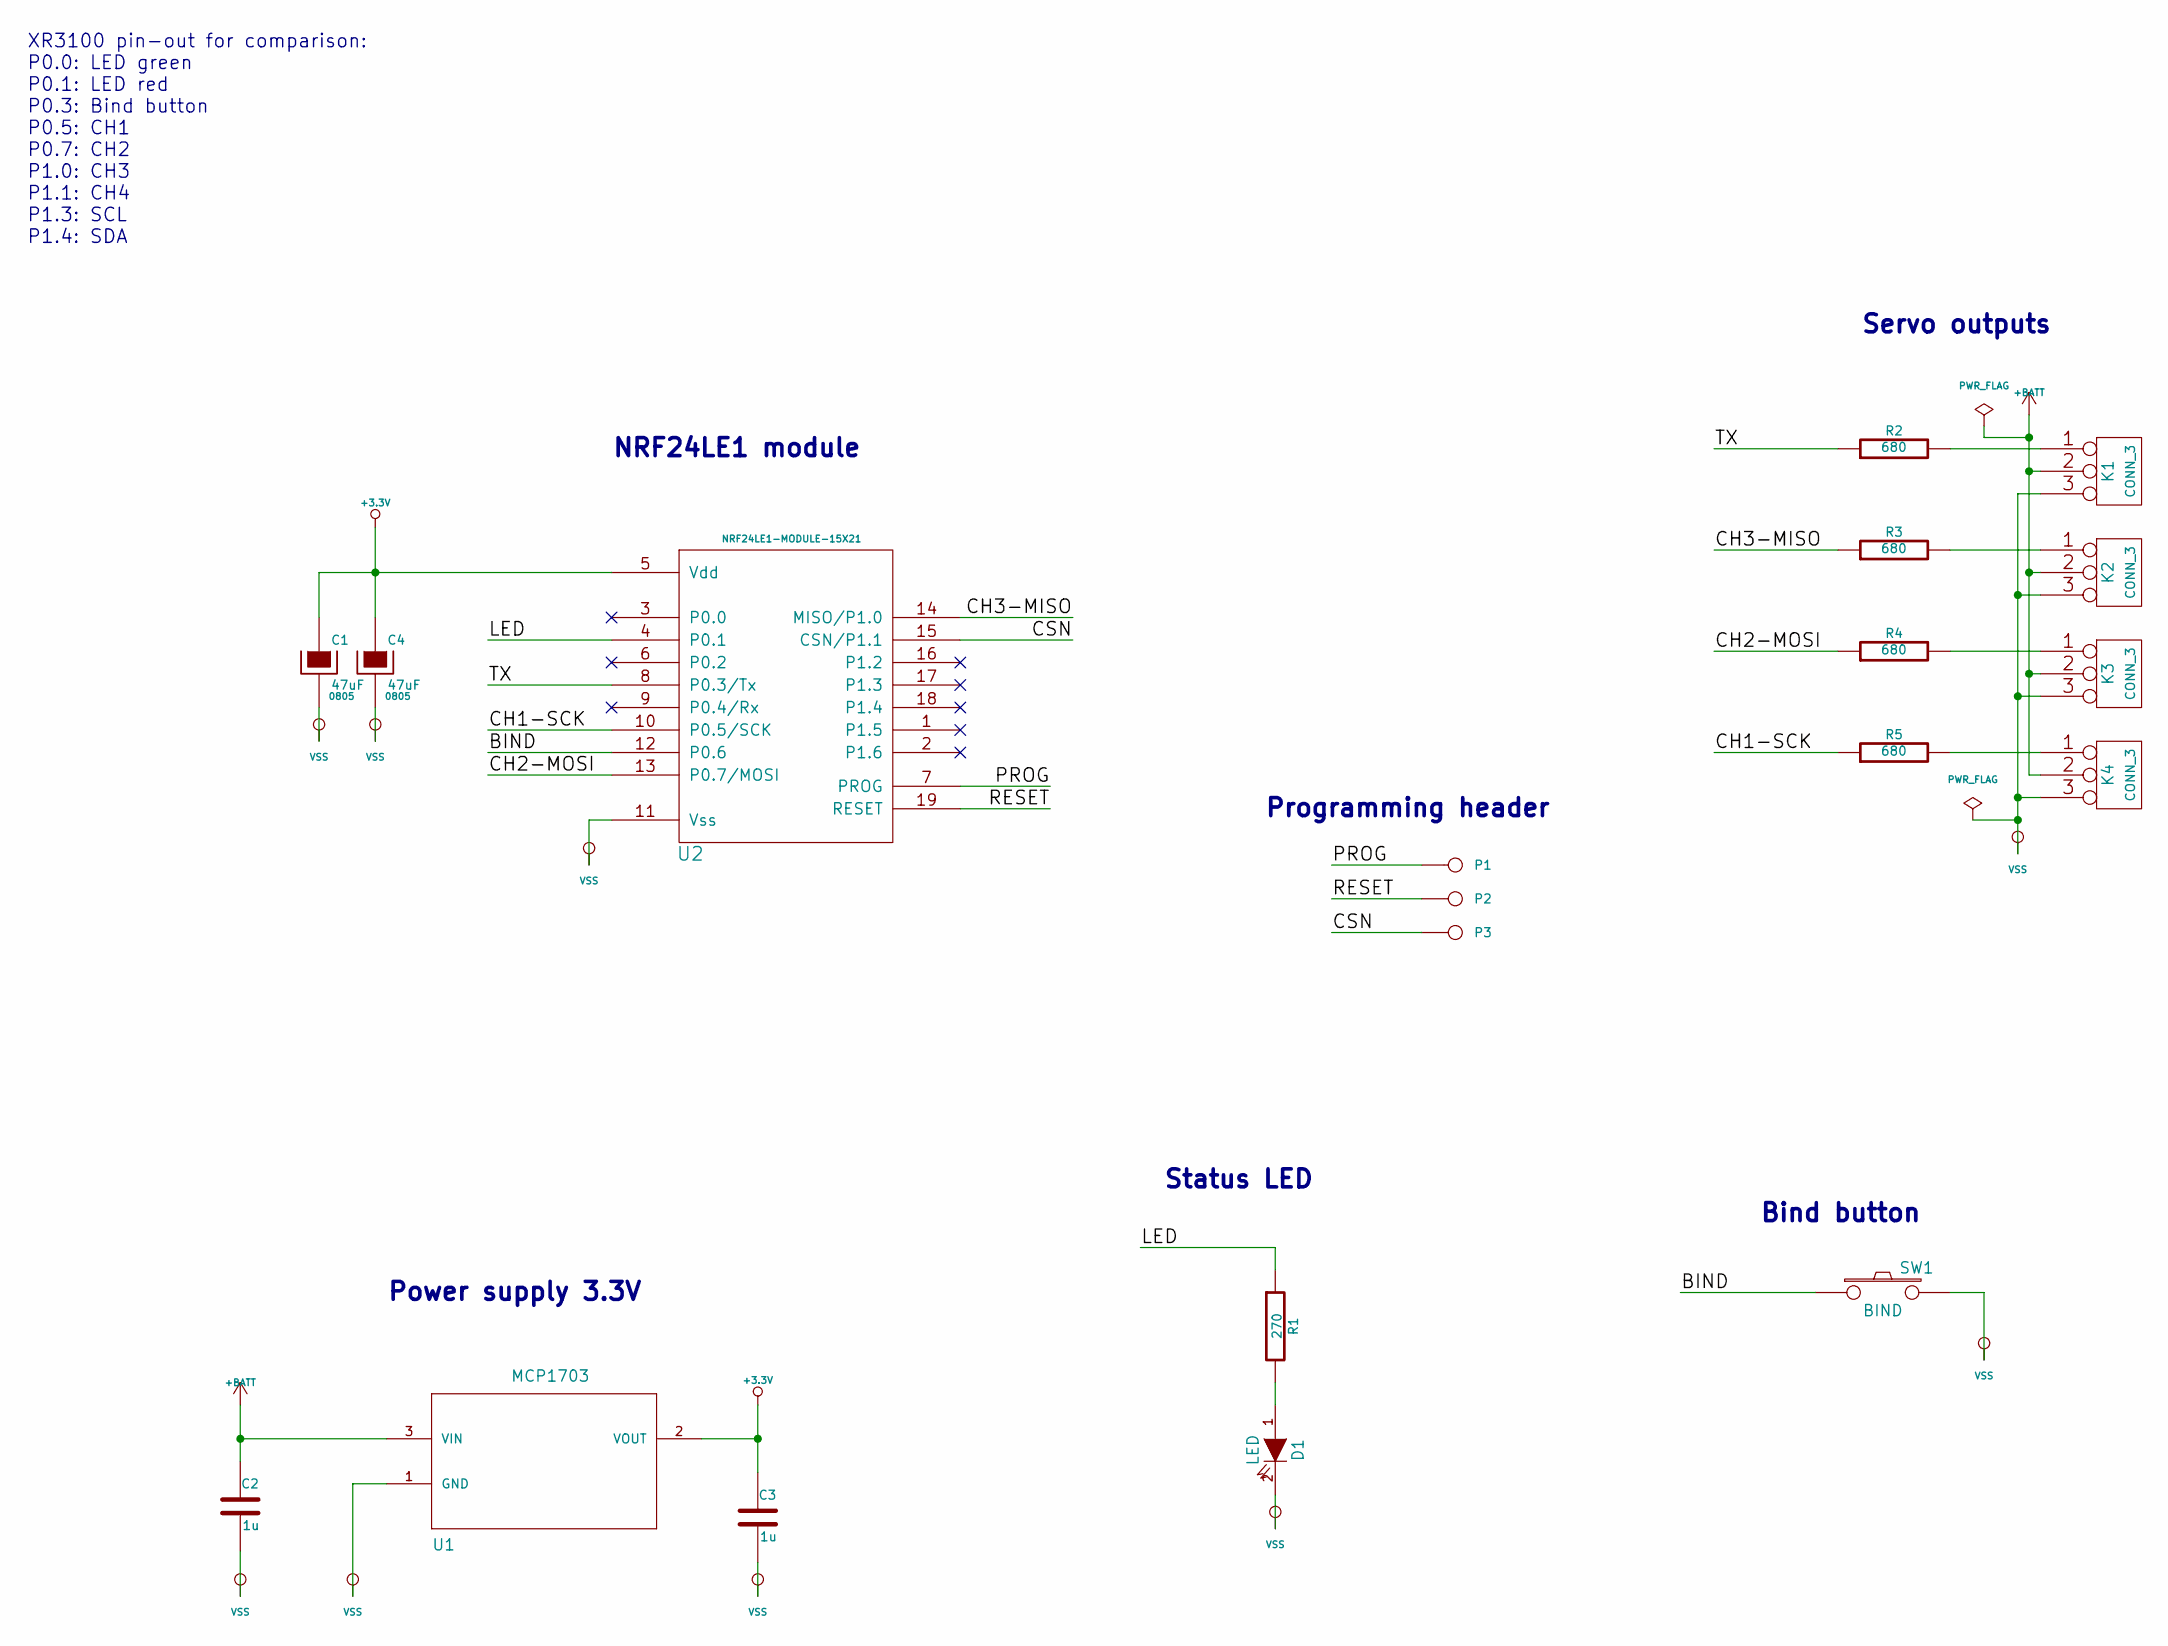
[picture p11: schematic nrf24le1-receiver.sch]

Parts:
C1, C4: 47uF; 0805
C2, C3: 1u
D1: LED
K1, K2, K3, K4: CONN_3
P1, P2, P3: CONN_1
R1: 270
R2, R3, R4, R5: 680
SW1: BIND
U1: MCP1703; MCP1703-SOT95P300X145-3N
U2: NRF24LE1-MODULE-15X21

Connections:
+3.3V: C1.1, C3.1, C4.1, U1.2 (VOUT), U2.5 (Vdd)
+BATT: C2.1, K1.2 (PM), K2.2 (PM), K3.2 (PM), K4.2 (PM), U1.3 (VIN)
/BIND: SW1.1, U2.12 (P0.6)
/CH1-SCK: R5.1, U2.10 (P0.5/SCK)
/CH2-MOSI: R4.1, U2.13 (P0.7/MOSI)
/CH3-MISO: R3.1, U2.14 (MISO/P1.0)
/CSN: P3.1, U2.15 (CSN/P1.1)
/LED: R1.1, U2.4 (P0.1)
/PROG: P1.1, U2.7 (PROG)
/RESET: P2.1, U2.19 (RESET)
/TX: R2.1, U2.8 (P0.3/Tx)
unnamed: K4.1, R5.2
unnamed: K1.1, R2.2
unnamed: K2.1, R3.2
unnamed: K3.1, R4.2
unnamed: D1.1 (A), R1.2
VSS: C1.2, C2.2, C3.2, C4.2, D1.2 (K), K1.3, K2.3, K3.3, K4.3, SW1.2, U1.1 (GND), U2.11 (Vss)

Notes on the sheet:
XR3100 pin-out for comparison: P0.0: LED green P0.1: LED red P0.3: Bind button P0.5: CH1 P0.7: CH2 P1.0: CH3 P1.1: CH4 P1.3: SCL P1.4: SDA
NRF24LE1 module
Programming header
Servo outputs
Status LED
Power supply 3.3V
Bind button

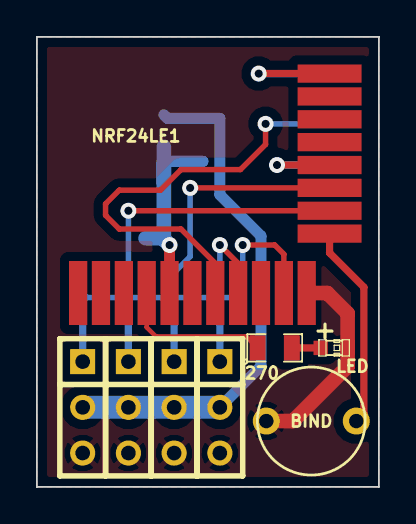
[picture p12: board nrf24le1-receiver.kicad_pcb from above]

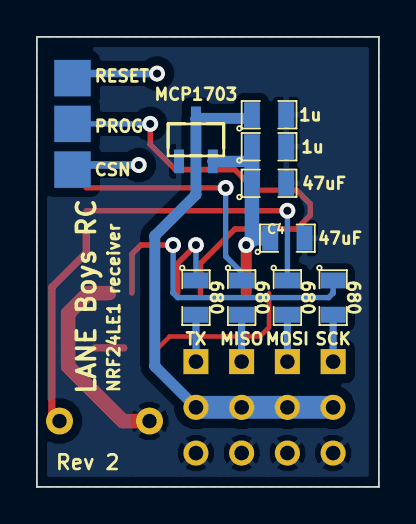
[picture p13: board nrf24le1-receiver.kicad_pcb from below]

Board: 2 copper layers, 19.0 x 25.0 mm, 20 parts (12 on the bottom side), 17 nets.

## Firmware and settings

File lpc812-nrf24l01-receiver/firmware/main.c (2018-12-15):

/******************************************************************************

    Application entry point.

    Contains the main loop and the hardware initialization.

******************************************************************************/
#include <stdio.h>
#include <stdbool.h>

#include <platform.h>
#include <uart0.h>
#include <spi.h>
#include <rc_receiver.h>
#include <preprocessor_output.h>

#include <LPC8xx_ROM_API.h>


#ifndef BAUDRATE
    #define BAUDRATE 115200
#endif


void SysTick_handler(void);
void PININT0_irq_handler(void);
void SCT_irq_handler(void);
void MRT_irq_handler(void);
void switch_gpio_according_rx_protocol(rx_protocol_t rx_protocol);



// Global flag that is true for one mainloop every __SYSTICK_IN_MS
bool systick;
volatile uint32_t milliseconds;

// Global flag indicating 8-channel hardware based on TSSOP20 version
bool is8channel;

uint32_t gpio_mask_led = (1 << GPIO_4CH_BIT_LED);
uint32_t gpio_mask_nrf_ce = (1 << GPIO_4CH_BIT_NRF_CE);

static volatile uint32_t systick_count;



// ****************************************************************************
static void feed_the_watchdog(void)
{
    LPC_WWDT->FEED = 0xaa;
    LPC_WWDT->FEED = 0x55;
}


// ****************************************************************************
static void service_systick(void)
{
    if (!systick_count) {
        systick = false;
        return;
    }

    systick = true;
    milliseconds += __SYSTICK_IN_MS;

    // Disable the SysTick interrupt. Use memory barriers to ensure that no
    // interrupt is pending in the pipeline.
    // More info:
    // http://infocenter.arm.com/help/index.jsp?topic=/com.arm.doc.dai0321a/BIHHFHJD.html
    SysTick->CTRL &= ~(1 << 1);
    __DSB();
    __ISB();
    --systick_count;
    SysTick->CTRL |= (1 << 1);      // Re-enable the system tick interrupt
}


// ****************************************************************************
static void stack_check(void)
{
#ifndef NO_DEBUG
    #define CANARY 0xcafebabe

    static uint32_t *last_found = (uint32_t *)(0x10001000 - 48);
    uint32_t *now;

    if (last_found == (uint32_t *)0x10000000) {
        return;
    }

    now = last_found;
    while (*now != CANARY && now > (uint32_t *)0x10000000) {
        --now;
    }

    if (now != last_found) {
        last_found = now;
        uart0_send_cstring("Stack down to 0x");
        uart0_send_uint32_hex((uint32_t)now);
        uart0_send_linefeed();
    }
#endif
}


// ****************************************************************************
static void init_hardware(void)
{
    int i;

#if __SYSTEM_CLOCK != 12000000
#error Clock initialization code expexts __SYSTEM_CLOCK to be set to 1200000
#endif


    if (is8channel) {
        gpio_mask_led = (1 << GPIO_8CH_BIT_LED);
        gpio_mask_nrf_ce = (1 << GPIO_8CH_BIT_NRF_CE);
    }


    // Set flash wait-states to 1 system clock
    LPC_FLASHCTRL->FLASHCFG = 0;


    // ------------------------
    // Turn on peripheral clocks for SCTimer, IOCON, SPI0, MRT, WWDT
    // (GPIO, SWM alrady enabled after reset)
    LPC_SYSCON->SYSAHBCLKCTRL |=
        (1 << 18) | (1 << 17) | (1 << 11) | (1 << 10) | (1 << 8);


    // ------------------------
    // Turn on brown-out detection and reset
    LPC_SYSCON->BODCTRL = (1 << 4) | (1 << 2) | (3 << 0);


    // ------------------------
    // Multi Rate Timer configuration
    // This timer is used for the delay_us functionality
    LPC_MRT->Channel[0].CTRL = (0x1 << 1); // One-shot mode


#ifdef USE_IRC
    // All special functions disabled, including reset
    LPC_SWM->PINENABLE0 = 0xffffffff;
#endif


#ifndef USE_IRC
    // XTALIN and XTALOUT enabled, others disabled (including reset)
    LPC_IOCON->PIO0_8 = 0;              // Turn pull-up off
    LPC_IOCON->PIO0_9 = 0;
    LPC_SWM->PINENABLE0 = 0xffffffcf;

    if (is8channel) {
        // A 12 MHz crystal is used on 8-channel hardware.
        // Directly used as system clock
        LPC_SYSCON->SYSOSCCTRL = (0 << 1);          // 1..20 MHz range

        LPC_SYSCON->PDRUNCFG &= ~(1 << 5);          // Enable the system oscillator
        delay_us(600);

        LPC_SYSCON->SYSPLLCLKSEL = 0x1;             // PLL input is the crystal oscillator
        LPC_SYSCON->SYSPLLCLKUEN = 0;               // Toggle PLL-enable
        LPC_SYSCON->SYSPLLCLKUEN = 1;

        LPC_SYSCON->MAINCLKSEL = 0x1;               // Use the PLL clock input as main clock
        LPC_SYSCON->MAINCLKUEN = 0;                 // Toggle CLK-enable
        LPC_SYSCON->MAINCLKUEN = 1;
    }
    else {
        // A 16 MHz crystal is used on 4-channel hardware, so we use the PLL
        // to make 48 MHz, then divide by 4 for 12 MHz system clock

        LPC_SYSCON->SYSOSCCTRL = (1 << 1);          // 15..25 MHz range
        LPC_SYSCON->PDRUNCFG &= ~(1 << 5);          // Enable the system oscillator
        delay_us(600);

        LPC_SYSCON->PDRUNCFG &= ~(1 << 7);          // Enable the PLL
        LPC_SYSCON->SYSPLLCLKSEL = 0x1;             // PLL input is the crystal oscillator
        LPC_SYSCON->SYSPLLCLKUEN = 0;               // Toggle PLL-enable
        LPC_SYSCON->SYSPLLCLKUEN = 1;

        // Set the PLL to 16Mhz * 3 = 48 Mhz
        LPC_SYSCON->SYSPLLCTRL = (0x2 << 0);        // M = 3

        while (!(LPC_SYSCON->SYSPLLSTAT & 1)) {     // Wait for PLL lock
            ;
        }

        LPC_SYSCON->SYSAHBCLKDIV = 4;               // Divide 48 MHz PLL output by 4 for 12 MHz system clock

        LPC_SYSCON->MAINCLKSEL = 0x3;               // Use the PLL clock output as main clock
        LPC_SYSCON->MAINCLKUEN = 0;                 // Toggle CLK-enable
        LPC_SYSCON->MAINCLKUEN = 1;
    }
#endif


    // ------------------------
    // IO configuration

    // Enable hardware inputs and outputs
    if (is8channel) {
        // 8ch pin configuration
#ifndef NO_DEBUG
        // When debug is active we enable the UART output on CH5
        LPC_SWM->PINASSIGN0 = (0xff << 24) |
                              (0xff << 16) |
                              (0xff << 8) |                     // UART0_RX
                              (GPIO_BIT_TX << 0);               // UART0_TX
#endif

        LPC_SWM->PINASSIGN3 = (GPIO_8CH_BIT_NRF_SCK << 24) |    // SPI0_SCK
                              (0xff << 16) |
                              (0xff << 8) |
                              (0xff << 0);

        LPC_SWM->PINASSIGN4 = (0xff << 24) |
                              (GPIO_8CH_BIT_NRF_CSN << 16) |    // SPI0_SSEL
                              (GPIO_8CH_BIT_NRF_MISO << 8) |    // SPI0_MISO
                              (GPIO_8CH_BIT_NRF_MOSI << 0);     // SPI0_MOSI

        // Make all servo outputs High initially
        LPC_GPIO_PORT->SET0 = (1 << GPIO_8CH_BIT_CH1) |
                              (1 << GPIO_8CH_BIT_CH2) |
                              (1 << GPIO_8CH_BIT_CH3) |
                              (1 << GPIO_8CH_BIT_CH4) |
                              (1 << GPIO_8CH_BIT_CH5) |
                              (1 << GPIO_8CH_BIT_CH6) |
                              (1 << GPIO_8CH_BIT_CH7) |
                              (1 << GPIO_8CH_BIT_CH8);

        // Configure outputs
        LPC_GPIO_PORT->DIR0 = (1 << GPIO_8CH_BIT_NRF_SCK) |
                              (1 << GPIO_8CH_BIT_NRF_MOSI) |
                              (1 << GPIO_8CH_BIT_NRF_CSN) |
                              (1 << GPIO_8CH_BIT_NRF_CE) |
                              (1 << GPIO_8CH_BIT_CH1) |
                              (1 << GPIO_8CH_BIT_CH2) |
                              (1 << GPIO_8CH_BIT_CH3) |
                              (1 << GPIO_8CH_BIT_CH4) |
                              (1 << GPIO_8CH_BIT_CH5) |
                              (1 << GPIO_8CH_BIT_CH6) |
                              (1 << GPIO_8CH_BIT_CH7) |
                              (1 << GPIO_8CH_BIT_CH8) |
                              (1 << GPIO_8CH_BIT_LED);
    }
    else {
        // 4ch pin configuration
        LPC_SWM->PINASSIGN0 = (0xff << 24) |
                              (0xff << 16) |
                              (0xff << 8) |                     // UART0_RX
                              (GPIO_BIT_TX << 0);               // UART0_TX

        LPC_SWM->PINASSIGN3 = (GPIO_4CH_BIT_NRF_SCK << 24) |    // SPI0_SCK
                              (0xff << 16) |
                              (0xff << 8) |
                              (0xff << 0);

        LPC_SWM->PINASSIGN4 = (0xff << 24) |
                              (GPIO_4CH_BIT_NRF_CSN << 16) |    // SPI0_SSEL
                              (GPIO_4CH_BIT_NRF_MISO << 8) |    // SPI0_MISO
                              (GPIO_4CH_BIT_NRF_MOSI << 0);     // SPI0_MOSI

        // Make all servo outputs High initially
        LPC_GPIO_PORT->SET0 = (1 << GPIO_4CH_BIT_CH1) |
                              (1 << GPIO_4CH_BIT_CH2) |
                              (1 << GPIO_4CH_BIT_CH3) |
                              (1 << GPIO_4CH_BIT_CH4);

        // Configure outputs
        LPC_GPIO_PORT->DIR0 = (1 << GPIO_4CH_BIT_NRF_SCK) |
                              (1 << GPIO_4CH_BIT_NRF_MOSI) |
                              (1 << GPIO_4CH_BIT_NRF_CSN) |
                              (1 << GPIO_4CH_BIT_NRF_CE) |
                              (1 << GPIO_4CH_BIT_CH1) |
                              (1 << GPIO_4CH_BIT_CH2) |
                              (1 << GPIO_4CH_BIT_CH3) |
                              (1 << GPIO_4CH_BIT_CH4) |
                              (1 << GPIO_4CH_BIT_LED);
    }

    // CE = 0; LED on
    LPC_GPIO_PORT->CLR0 = gpio_mask_led | gpio_mask_nrf_ce;


    // ------------------------
    // Configure SCTimer globally for two 16-bit counters
    LPC_SCT->CONFIG = 0;
    LPC_SCT->CTRL_H |= (1 << 3) | (1 << 2);         // Reset and Halt Counter H
    LPC_SCT->CTRL_L |= (1 << 3) | (1 << 2);         // Reset and Halt Counter L

    // Timer H is used for the servo outputs, setting the servo pins
    // on timer reload and clearing them when a match condition occurs.
    // Up to 4 servo pulses are generated with MATCH/EVENT registers 1..4 and
    // corresponding timer outputs 0..3.
    // MATCH/EVENT register 0 is used for auto-reload of the timer period.

    // Set up the events that the match registers trigger. EVENT[0] is for the
    // servo pulse period, EVENTS[1..4] for 4 servo channel outputs.
    // All 5 events are setup in the same way:
    //    - Event happens in all states
    //    - Match register of the same number
    //    - HEVENT: Match counter H
    //    - COMBMODE: Match condition only
    for (i = 0; i < 5; i++) {
        LPC_SCT->EVENT[i].STATE = 0xFFFF;           // Event happens in all states
        LPC_SCT->EVENT[i].CTRL = (i << 0) |         // Match register
                                 (1 << 4) |         // Select H counter
                                 (0x1 << 12);       // Match condition only
    }
    LPC_SCT->LIMIT_H = (1 << 0);                    // EVENT0 limits (resets) the counter

    LPC_SCT->OUTPUT = (1 << 0) |                    // Force all timer outputs initially High
                      (1 << 1) |
                      (1 << 2) |
                      (1 << 3);

    // 8-channel multiplexing
    //
    // All 4 channel events are triggering an interrupt. Whenever an event fires,
    // we load the corresponding MATCHREL with the value for the other servo
    // channel, and CTOUT with the port number of that other servo channel.
    // The next EVENT0 reseting the timer will output the other channel and
    // the cycle repeats.


    // All servo outputs will be SET with timer reload event 0, and CLEARED
    // with the indivual servo pulse time EVENTs
    LPC_SCT->OUT[0].SET = (1 << 0);
    LPC_SCT->OUT[1].SET = (1 << 0);
    LPC_SCT->OUT[2].SET = (1 << 0);
    LPC_SCT->OUT[3].SET = (1 << 0);

    LPC_SCT->OUT[0].CLR = (1 << 1);                 // Event 1 will clear CTOUT_0
    LPC_SCT->OUT[1].CLR = (1 << 2);                 // Event 2 will clear CTOUT_1
    LPC_SCT->OUT[2].CLR = (1 << 3);                 // Event 3 will clear CTOUT_2
    LPC_SCT->OUT[3].CLR = (1 << 4);                 // Event 4 will clear CTOUT_3


    // Timer L is used for frequency hopping. It is configured as a simple
    // auto-reload that fires an interrupt in regular intervals, using EVENT[5].
    // The rc_receiver.c takes care of setting the counter and limit values.

    LPC_SCT->CTRL_L |= (1 << 3) | (1 << 2) |        // Reset and Halt Counter L
        (((__SYSTEM_CLOCK / 1000000) - 1) << 5);    // PRE_L[12:5] = divide for 1 MHz
    LPC_SCT->EVENT[5].STATE = 0xFFFF;               // Event happens in all states
    LPC_SCT->EVENT[5].CTRL = (0 << 0) |             // Match register
                             (0 << 4) |             // Select counter L
                             (0x1 << 12);           // Match condition only
    LPC_SCT->LIMIT_L = (1u << 5);                   // EVENT[5] limits (resets) the counter
    LPC_SCT->EVEN |= (1u << 5);                     // EVENT[5] generates an interrupt


    // ------------------------
    // Configure the exernal interrupt from the NRF chip
    LPC_SYSCON->PINTSEL[0] = is8channel ? GPIO_8CH_BIT_NRF_IRQ : GPIO_4CH_BIT_NRF_IRQ; // NRF_IRQ on PININT0
    LPC_PIN_INT->IENF = (1 << 0);               // Enable falling edge on PININT0


    // ------------------------
    // Watchdog configuration
    LPC_SYSCON->WDTOSCCTRL = (1 << 5) |     // 0.6 MHz
                             (0xff << 0);   // Divide by 64 for ~9.4 kHz Watchdog clock
    LPC_SYSCON->PDRUNCFG &= ~(1 << 6);      // Watchdog oscillator on
    LPC_WWDT->MOD = (1 << 0) |              // Watchdog enabled
                    (1 << 1);               // Watchdog causes reset
    // Set approx 200ms watchdog timeout.
    // The application can use more than 100ms when erasing a single page
    // of flash, so we give us more than that.
    LPC_WWDT->TC = 2000;
    feed_the_watchdog();

    // ------------------------
    // SysTick configuration
    SysTick->LOAD = __SYSTEM_CLOCK * __SYSTICK_IN_MS / 1000;
    SysTick->VAL = __SYSTEM_CLOCK * __SYSTICK_IN_MS / 1000;
    SysTick->CTRL = (1 << 0) |              // Enable System Tick counter
                    (1 << 1) |              // System Tick interrupt enable
                    (1 << 2);               // Use system clock

}


// ****************************************************************************
static void init_hardware_final(void)
{
    // Turn off peripheral clock for IOCON to preserve power
    LPC_SYSCON->SYSAHBCLKCTRL &= ~(1 << 18);

    NVIC_EnableIRQ(PININT0_IRQn);
    NVIC_EnableIRQ(SCT_IRQn);
}


// ****************************************************************************
void switch_gpio_according_rx_protocol(rx_protocol_t protocol)
{
    // HaLt the counter. This is required before changing bits in the
    // CTRL register other than HALT or STOP.
    LPC_SCT->CTRL_H = (1 << 2);

    if (is8channel && (protocol == PROTOCOL_8CH)) {
        // The timer is running at 2 MHz clock (500ns resolution).
        LPC_SCT->CTRL_H = (1 << 3) | (1 << 2) |
          (((__SYSTEM_CLOCK / 2000000) - 1) << 5);

        // The repeat frequency is 8ms, leading to a pulse repeat rate of 16ms
        // because we process 2 sets of 4 servo outputs.
        // NOTE: Hitec HS65-HB don't work well with 10ms repeat rate, but fine
        // with 16 or above
        LPC_SCT->MATCHREL[0].H = (8000 * 2) - 1;

        // Servo pulse 1.5 ms intially
        LPC_SCT->MATCHREL[1].H = SERVO_PULSE_CENTER * 2;
        LPC_SCT->MATCHREL[2].H = SERVO_PULSE_CENTER * 2;
        LPC_SCT->MATCHREL[3].H = SERVO_PULSE_CENTER * 2;
        LPC_SCT->MATCHREL[4].H = SERVO_PULSE_CENTER * 2;

        // EVENT[1..4] generate an interrupt
        LPC_SCT->EVEN |= (1u << 1) |
                         (1u << 2) |
                         (1u << 3) |
                         (1u << 4);
    }
    else {
        // The timer is running at 1.3 MHz clock (750ns resolution).
        // The repeat frequency is 10ms (a multiple of the on-air packet repeat
        // rate).
        LPC_SCT->CTRL_H = (1 << 3) | (1 << 2) |
          (((__SYSTEM_CLOCK / 1333333) - 1) << 5);

        // 10 ms servo pulse repeat time
        LPC_SCT->MATCHREL[0].H = (10000 * 4 / 3) - 1;

        // Servo pulse 1.5 ms intially
        LPC_SCT->MATCHREL[1].H = SERVO_PULSE_CENTER * 4 / 3;
        LPC_SCT->MATCHREL[2].H = SERVO_PULSE_CENTER * 4 / 3;
        LPC_SCT->MATCHREL[3].H = SERVO_PULSE_CENTER * 4 / 3;
        LPC_SCT->MATCHREL[4].H = SERVO_PULSE_CENTER * 4 / 3;

        // EVENT[1..4] DON'T generate an interrupt
        LPC_SCT->EVEN &= ~((1u << 1) |
                           (1u << 2) |
                           (1u << 3) |
                           (1u << 4));

        if (is8channel) {
            LPC_SWM->PINASSIGN6 = (GPIO_8CH_BIT_CH1 << 24) |        // CTOUT_0
                                  (0xff << 16) |
                                  (0xff << 8) |
                                  (0xff << 0);

            LPC_SWM->PINASSIGN7 = (0xff << 24) |
                                  (GPIO_8CH_BIT_CH4 << 16) |        // CTOUT_3
                                  (GPIO_8CH_BIT_CH3 << 8) |         // CTOUT_2
                                  (GPIO_8CH_BIT_CH2 << 0);          // CTOUT_1
        }
        else {
            LPC_SWM->PINASSIGN6 = (GPIO_4CH_BIT_CH1 << 24) |        // CTOUT_0
                                  (0xff << 16) |
                                  (0xff << 8) |
                                  (0xff << 0);

            LPC_SWM->PINASSIGN7 = (0xff << 24) |
                                  (0xff << 16) |                    // CTOUT_3 (by default we enable the UART output!)
                                  (GPIO_4CH_BIT_CH3 << 8) |         // CTOUT_2
                                  (GPIO_4CH_BIT_CH2 << 0);          // CTOUT_1
        }
    }


    if (is8channel) {
        // 8ch hardware
        switch (protocol) {
            case PROTOCOL_8CH:
#ifdef NO_DEBUG
                // Disable UART0_TX
                LPC_SWM->PINASSIGN0 |= (0xff << 0);
#endif
                break;

            case PROTOCOL_3CH:
            case PROTOCOL_4CH:
            default:
                // Enable UART0_TX
                // Since the TX pin is on (unused) CH5 we can use it as
                // preprocessor output regardless weather the protocol is 3ch
                // or 4ch
                LPC_SWM->PINASSIGN0 = (0xff << 24) |
                                      (0xff << 16) |
                                      (0xff << 8) |
                                      (GPIO_BIT_TX << 0);
                break;
        }

        return;
    }

    // 4ch hardware
    switch (protocol) {
        case PROTOCOL_4CH:
        case PROTOCOL_8CH:
#ifdef NO_DEBUG
            // Disable UART0_TX
            LPC_SWM->PINASSIGN0 |= (0xff << 0);

            // Enable CH4 on CTOUT_3 without disturbing the other settings
            LPC_SWM->PINASSIGN7 = (LPC_SWM->PINASSIGN7 & 0xff00ffff) | (GPIO_4CH_BIT_CH4 << 16);
#endif
            break;

        case PROTOCOL_3CH:
        default:
            // Disable CTOUT_3 (CH4)
            LPC_SWM->PINASSIGN7 |= (0xff << 16);

            // enable UART0_TX
            LPC_SWM->PINASSIGN0 = (0xff << 24) |
                                  (0xff << 16) |
                                  (0xff << 8) |
                                  (GPIO_BIT_TX << 0);
            break;
    }

}


// ****************************************************************************
void PININT0_irq_handler(void)
{
    LPC_PIN_INT->IST = (1 << 0);          // Clear the interrupt status flag
    rf_interrupt_handler();
}


// ****************************************************************************
void SCT_irq_handler(void)
{
    if (LPC_SCT->EVFLAG & (1u << 5)) {
        LPC_SCT->EVFLAG = (1u << 5);
        hop_timer_handler();
    }

    // Events 1..4 for 8ch multiplexing
    if (LPC_SCT->EVFLAG & ((1u << 1) | (1u << 2) | (1u << 3) | (1u << 4))) {
      // Note: flags are cleared within the function!
      servo_pulse_timer_handler();
    }
}


// ****************************************************************************
void SysTick_handler(void)
{
    if (SysTick->CTRL & (1 << 16)) {       // Read and clear Countflag
        ++systick_count;
    }
}


// ****************************************************************************
void invoke_ISP(void)
{
    unsigned int param[5];

    // Release all special function pins
    LPC_SWM->PINASSIGN0 = 0xffffffff;
    LPC_SWM->PINASSIGN1 = 0xffffffff;
    LPC_SWM->PINASSIGN2 = 0xffffffff;
    LPC_SWM->PINASSIGN3 = 0xffffffff;
    LPC_SWM->PINASSIGN4 = 0xffffffff;
    LPC_SWM->PINASSIGN5 = 0xffffffff;
    LPC_SWM->PINASSIGN6 = 0xffffffff;
    LPC_SWM->PINASSIGN7 = 0xffffffff;
    LPC_SWM->PINASSIGN8 = 0xffffffff;

    // Make the ISP RX pin an input
    LPC_GPIO_PORT->DIR0 &= ~(1 << 0);

    // Disable the watchdog through power-down of the watchdog osc
    LPC_SYSCON->PDRUNCFG |= (1 << 6);

    param[0] = 57;  // Reinvoke ISP
    __disable_irq();
    iap_entry(param, param);
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
int main(void)
{
    // is8channel gets set if MCU is LPC812M101JDH20 (20 pin TSSSOP version)
    is8channel = (LPC_SYSCON->DEVICE_ID == 0x00008122);

    init_hardware();
    init_uart0(BAUDRATE);
    init_spi();
    init_hardware_final();

#ifndef NO_DEBUG
    uart0_send_cstring("Hardware initialized\n");
#endif

    // Wait a for a short time after power up before talking to the nRF24
    delay_us(20000);
    init_receiver();

#ifndef NO_DEBUG
    uart0_send_cstring("Receiver initialized\n");
#endif

    for (;;) {
        service_systick();
        process_receiver();

#ifdef ENABLE_PREPROCESSOR_OUTPUT
        output_preprocessor();
#endif

        stack_check();
        feed_the_watchdog();
    }
}

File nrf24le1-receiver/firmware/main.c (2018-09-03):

/******************************************************************************

    Application entry point.

    Contains the main loop and the hardware initialization.

******************************************************************************/
#include <stdio.h>
#include <stdbool.h>

#include <platform.h>
#include <uart0.h>
#include <spi.h>
#include <rc_receiver.h>
#include <preprocessor_output.h>


#define TIMER_16_MS     TIMER_VALUE_US(16000)
#define TIMER_150_US    TIMER_VALUE_US(150)


extern bool successful_stick_data;


// Global flag that is true for one mainloop every __SYSTICK_IN_MS
bool systick;

static volatile uint8_t systick_count;


// ****************************************************************************
// Prototypes for the interrupt handlers located in other files
// They need to reside here as SDCC assigns the vectors only for prototypes
// located in the file that contains the main() function,
void rf_interrupt_handler(void) __interrupt ((0x004b - 3) / 8);
void hop_timer_handler(void) __interrupt ((0x002b - 3) / 8);
void servo_pulse_timer_handler(void) __interrupt ((0x001b - 3) / 8) __using (1);



// ****************************************************************************
// Timer 0 interrupt handler
void timer0_isr(void) __interrupt ((0x000b - 3) / 8)
{
    TIMER0 = TIMER_16_MS;
    ++systick_count;

    if (successful_stick_data) {
        // Start timer1 with a very short interval to kick off one set of
        // servo pulses
        TIMER1 = TIMER_150_US;
        TCON_tr1 = 1;
    }
}


// ****************************************************************************
static void service_systick(void)
{
    if (!systick_count) {
        systick = false;
        return;
    }

    --systick_count;
    systick = true;
}


// ****************************************************************************
static void init_hardware(void)
{
    // Due to varying hardware the IO initialization is a macro in platform.h
    GPIO_INIT();

    TCON = 0;               // Clear Timer0 and Timer1 flags, stop both timers
    TMOD = 0x11;            // Set Timer0 and Timer1 as 16 bit timer

    TIMER0 = TIMER_16_MS;

    IEN0_tf0 = 1;           // Enable Timer0 interrupt
    IEN0_tf1 = 1;           // Enable Timer1 interrupt
    IEN0_tf2 = 1;           // Enable Timer2 interrupt
    IEN1_rfirq = 1;

    TCON_tr0 = 1;           // Start Timer0

    IP0 = (1 << 3);         // Timer1 interrupt has higher priority than the rest
    IP1 = (1 << 3);
}


// ****************************************************************************
static void init_hardware_final(void)
{
    IEN0_all = 1;
}


// ****************************************************************************
void delay_us(uint16_t microseconds)
{
    volatile uint8_t dummy;

    // Spot-on for larger timeouts (verifyed with an oscilloscope)

    microseconds >>= 1;

    dummy = 0;
    while (microseconds--) {
        ++dummy;
        ++dummy;
        ++dummy;
        ++dummy;
    }
}


// ****************************************************************************
int main(void)
{
    init_hardware();
#ifndef NO_DEBUG
    init_uart0();
#endif
    init_spi();
    init_hardware_final();

#ifndef NO_DEBUG
    uart0_send_cstring("Hardware initialized\n");
#endif

    // Wait a for a short time after power up before talking to the nRF24
    delay_us(20000);
    init_receiver();

#ifndef NO_DEBUG
    uart0_send_cstring("Receiver initialized\n");
#endif

    while (1) {
        service_systick();
        process_receiver();

#ifdef ENABLE_PREPROCESSOR_OUTPUT
        output_preprocessor();
#endif
    }
}

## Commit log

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2014-11-21 Add KICAD project draft
    [lpc812-nrf24l01-receiver.kicad_pcb, lpc812-nrf24l01-receiver.sch]
2014-11-21 More tweaks to schematics and LPC812 symbol
    [lpc812-nrf24l01-receiver.kicad_pcb, lpc812-nrf24l01-receiver.sch]
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2014-11-21 Add switches library for SMD tact switches we have
    [lpc812-nrf24l01-receiver.kicad_pcb]
2014-11-22 Change pin-out for better layout
    [lpc812-nrf24l01-receiver.kicad_pcb, lpc812-nrf24l01-receiver.sch]
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2014-11-23 Implement LED logic, failsafe and binding completely
    Now the receiver is almost feature complete!
    [main.c, rc_receiver.c]
2014-11-23 Output servo pulses only after a valid stick data packet was received after reset
    [main.c, rc_receiver.c]
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2014-11-23 Re-layout the board, add protection resistors
    [lpc812-nrf24l01-receiver.kicad_pcb, lpc812-nrf24l01-receiver.sch]
2014-11-23 Tweak the board and use NXP footprints
    [lpc812-nrf24l01-receiver.kicad_pcb, lpc812-nrf24l01-receiver.sch]
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2014-11-24 Use new component libraries
    [lpc812-nrf24l01-receiver.kicad_pcb]
2014-11-24 Start working on the silk screen
    [lpc812-nrf24l01-receiver.kicad_pcb, lpc812-nrf24l01-receiver.sch]
2014-11-24 Tweak the footprints and board
    [lpc812-nrf24l01-receiver.kicad_pcb]
2014-11-25 More tweaking and playing around with silk screen and coordinates
    [lpc812-nrf24l01-receiver.kicad_pcb, lpc812-nrf24l01-receiver.sch]
2014-11-25 Fix persistent storage reading values back wrongly
    [persistent_storage.c]
2014-11-25 Fix issue with initial delay hanging
    [main.c]
2014-11-25 Add fault code for copy-to-ram error message
    [persistent_storage.c]
2014-11-25 Re-layout the board with different servo connector positions
    [lpc812-nrf24l01-receiver.kicad_pcb]
2014-11-26 Tweak board for least amount of vias; Add more silk screen
    [lpc812-nrf24l01-receiver.kicad_pcb, lpc812-nrf24l01-receiver.sch]
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2014-11-26 Fix library silkscreen being on the wrong layer
    [lpc812-nrf24l01-receiver.kicad_pcb]
2014-11-26 More silk screen tweaking
    [lpc812-nrf24l01-receiver.kicad_pcb]
2014-11-26 Make fonts a bit slimmer
    [lpc812-nrf24l01-receiver.kicad_pcb]
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2014-11-27 Implement using the crystal oscillator
    [main.c]
2014-11-27 Fix via alignmnet, add LED to silk screen
    [lpc812-nrf24l01-receiver.kicad_pcb]
2014-11-27 Use Multicomp switches we have. Rename library to proper name
    [lpc812-nrf24l01-receiver.kicad_pcb, lpc812-nrf24l01-receiver.sch]
2014-11-27 Tweak silkscreen of LED
    [lpc812-nrf24l01-receiver.kicad_pcb]
2014-11-27 Change components to 0805 which we have in stock
    [lpc812-nrf24l01-receiver.kicad_pcb, lpc812-nrf24l01-receiver.sch]
2014-11-27 Make the push button better
    [lpc812-nrf24l01-receiver.kicad_pcb, lpc812-nrf24l01-receiver.sch]
2014-11-28 Improve lock-on behaviour
    It has something to do with the first SCTimer, not sure what
    the issue is.
    [main.c, rc_receiver.c]
2014-11-29 Start on NRF24LE1 based receiver hardware
    [nrf24le1-receiver.kicad_pcb, nrf24le1-receiver.sch]
2014-11-29 Work on the layout of the NRF24LE1 receiver
    [nrf24le1-receiver.kicad_pcb]
2014-11-29 Tweak schematics and layout
    [nrf24le1-receiver.kicad_pcb, nrf24le1-receiver.sch]
2014-11-29 Fix initial hop timer not firing correctly.
    The MATCH register needs to be used for the first hop, and
    the COUNT register must be cleared. RTFM...
    [main.c, rc_receiver.c]
2014-11-29 Use round tact switch, tidy up the board
    [nrf24le1-receiver.kicad_pcb]
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2014-11-30 Make pinout similar to XR3100
    [nrf24le1-receiver.kicad_pcb, nrf24le1-receiver.sch]
2014-11-30 Finalize boards and make combined Gerbers for manufacturing
    [lpc812-nrf24l01-receiver-append.kicad_pcb, nrf24le1-receiver.kicad_pcb, nrf24le1-receiver.sch]
2014-11-30 Add PDF of the schematics
    [lpc812-nrf24l01-receiver.sch]
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2014-12-01 Fix read register being faulty after refactoring
    [rf.c]
2014-12-02 Turn off brown-out reset
    [nrf_spi_if.asm]
2014-12-02 Fix page erase process by waiting for WREN to be cleared
    [nrf_spi_program_firmware.py]
2014-12-02 Debug the code, functions mostly working but RF not tested yet
    Timer interrupt, UART, Binding, Persistent storage; all working!
    [main.c, persistent_storage.c, platform.h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]
2014-12-02 Reverse the PPM output polarity
    [rc_receiver.c]
2014-12-04 Restore brown-out removal, was not the issue
    [nrf_spi_if.asm]
2014-12-04 Change brown-out reset level to 2.8V
    [main.c]
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2014-12-12 Major refactoring of directory structure
    [lpc812-nrf24l01-receiver-append.kicad_pcb, lpc812-nrf24l01-receiver.kicad_pcb, lpc812-nrf24l01-receiver.sch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]
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2014-12-25 Fix IOs and persistent storage location for actual hardware
    [main.c, platform.h]
2014-12-25 Work on crystal oscillator. Not functional yet
    [main.c]
2014-12-26 Fix crystal oscillator usage, now working
    [main.c, uart0.c]
2014-12-26 Fix unwanted UART output when NO_DEBUG
    [rc_receiver.c]
2014-12-26 Fix preprocessor output, now all working
    [platform.h, preprocessor_output.c]
2014-12-26 Fix preprocessor; not tested yet
    [platform.h, preprocessor_output.c]
2014-12-27 Fix preprocessor output, now working
    [preprocessor_output.c]
2014-12-27 Fix timer documentation and initial servo pulse. repeat time now 10ms
    [main.c]
2015-01-05 Add 2x 47uF 0805 tantalum bypass cap to combat brown-outs
    [nrf24le1-receiver.kicad_pcb, nrf24le1-receiver.sch]
2015-01-05 Add 100uF cap against brown-out, add pull-down to prevent floating MISO
    [lpc812-nrf24l01-receiver.kicad_pcb, lpc812-nrf24l01-receiver.sch]
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2016-04-28 Add PCB (breadboard simulation) draft.
    Adjust pin-out according to best fit
    [programming-box.kicad_pcb, programming-box.sch]
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2016-05-20 Make blink program work, fix OpenOCD usage
    [main.c]
2016-05-20 Fix UART, now working
    [main.c]
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2016-05-23 Fix sound_play parameter order
    [main.c]
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2016-05-23 Fix new sound playback and let CPU sleep
    [main.c]
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2016-05-24 Fix servo pulse in microseconds, not milliseconds
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2016-05-27 nRF24L01 CE tied to Vcc; Add smoothing cap for battery measurement
    Add 4-pin socket for BT module
    [stm32f1-nrf24l01-transmitter.kicad_pcb, stm32f1-nrf24l01-transmitter.sch]
2016-05-28 LED is off after reset
    [main.c]
2016-05-28 Fix data type for ADC input buffer
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2016-05-29 Annotate the PCB and increase track widths for better visibility
    [stm32f1-nrf24l01-transmitter.kicad_pcb]
2016-05-31 Move ADC dump test function into mainloop to keep interrupt short
    [main.c]
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2016-05-31 Stop binding after a configurable timeout
    This is necessary as the PA in the nRF module from AliExpress
    even boosts the -18dBm signal, leading to a long range where
    the bind data can be received. In order to not interfere with other
    people it is best to keep binding only on for a short time.
    [main.c]
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2016-06-04 Add measurement from an almost empty 800mAh battery until shutoff
    [2016-06-04_Sony800mAh-3.63V-to-shutoff.csv]
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2016-06-05 Fix filename for CSV file
    [2016-06-05-Sony800mAh-full-to-shutoff.csv]
2016-06-05 Add chart for full discharge and change battery alarms according to findings
    [2016-06-05-Sony800mAh-full-to-shutoff.ods]
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2016-06-11 Update architecture document due to issue with rf power during binding
2016-06-11 Fix logging of structure output
    [main.c]
2016-06-11 Remove LED_dim function and fix issue with brightness being zero
    Since LED_init was called before CONFIG_init, the brightness was read as 0
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2016-06-12 Add songs made by Patrick for config broken, PB connecting/disconnecting
    [main.c]
2016-06-12 Add failsafe config and add music if config is invalid
    [main.c]
2016-06-12 Add unused inputs as switches and configure them as inputs
    [stm32f1-nrf24l01-transmitter.sch]
2016-06-13 Remove STM32F1 transmitter, it is now in a separate repository
    [2016-06-04_Sony800mAh-3.63V-to-shutoff.csv, 2016-06-04_Sony800mAh-3.63V-to-shutoff.ods, 2016-06-05-Sony800mAh-full-to-shutoff.csv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]
2016-06-13 Remote programming box, was meant for the STM32F1 transmitter
    [programming-box.kicad_pcb, programming-box.sch]
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2018-09-08 Fix servo glitching issue
    [rc_receiver.c]
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2018-09-12 Fix servo outputs and clean up the code
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2018-09-13 Fix issue with hanging on RX transmit
    [main.c]
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2018-09-17 Add correct symbol for nRF24 module
    [lpc812-nrf24l01-8ch-receiver.kicad_pcb, lpc812-nrf24l01-8ch-receiver.sch]
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2018-09-21 Changel to 2520 crystal to shrink board to 21x21 mm
    [lpc812-nrf24l01-8ch-receiver.kicad_pcb, lpc812-nrf24l01-8ch-receiver.sch]
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2018-09-26 Move all LPC812 versions to the same base directory
    Since the firmware will be shared it makes sense to keep them
    together
    [lpc812-nrf24l01-8ch-receiver.kicad_pcb, lpc812-nrf24l01-8ch-receiver.sch, lpc812-nrf24l01-receiver.kicad_pcb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]
2018-09-27 Change crystal of 8ch version to 16 MHz
    [lpc812-nrf24l01-8ch-receiver.sch]
2018-09-27 Make PIO10 and PIO11 use as input pins as they are open drain
    [lpc812-nrf24l01-8ch-receiver.kicad_pcb, lpc812-nrf24l01-8ch-receiver.sch]
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2018-09-29 Change crystal to 12 MHz and add schematics annotations
    [lpc812-nrf24l01-8ch-receiver.sch]
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2018-10-12 Fix connector label
    [lpc812-nrf24l01-8ch-receiver.kicad_pcb, lpc812-nrf24l01-8ch-receiver.sch]
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2018-10-24 FIX DEVICE_ID pointing to the wrong address!
2018-10-25 Make the crystal oscillator work for 8ch version
    The PLL is not used in the 8ch version.
    The 4ch version has changed to use the post divider of the PLL
    instead of the AHB divider by 4.
    This way the clock that the UART sees is the same in all cases.
    This also affects the IOCON module, to be checked if we need
    to change anything.
    [main.c, uart0.c]
2018-10-25 Implement storing of 8ch channel and failsafe data
    [rc_receiver.c]
2018-10-25 Fix pinout for both 4ch and 8ch version
    MISO and IRQ are swapped between them
    [platform.h]
2018-10-25 Make basic 3ch protocol receiving and binding work
    [main.c, persistent_storage.c, rc_receiver.c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]
2018-10-26 Implement 8ch binding, not tested yet
    [rc_receiver.c]
2018-10-26 Change LED resistor value
    Update library to latest version of KiCad
    [lpc812-nrf24l01-8ch-receiver.sch]
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2018-11-04 Fix output channels in 8ch mode
    [rc_receiver.c]
2018-11-21 Add RF simulation and make receiver work
    Turns out the issue was that CH1 and CH2 had a solder bridge
    on the LPC812...
    [main.c, rc_receiver.c]
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2018-11-29 Fix comment on PLL clock
    [main.c]
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
